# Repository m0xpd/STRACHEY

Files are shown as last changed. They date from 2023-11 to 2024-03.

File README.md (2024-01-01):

# STRACHEY

<p width=100%, align="center">
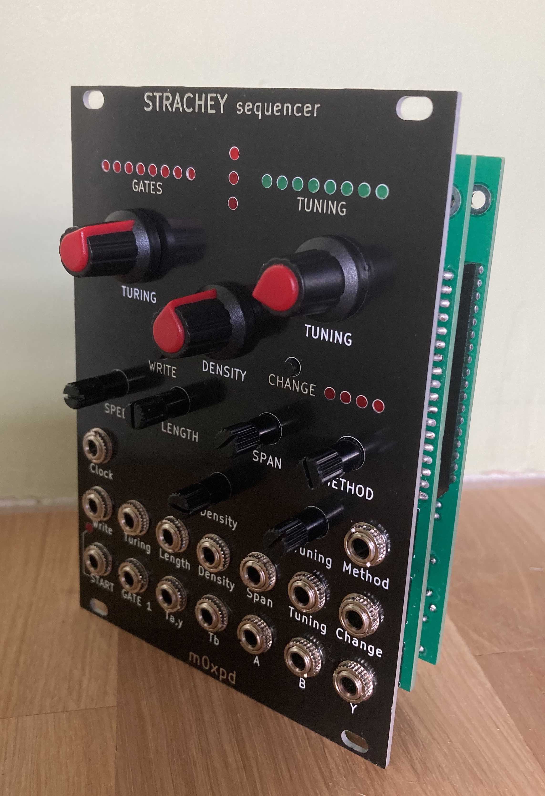
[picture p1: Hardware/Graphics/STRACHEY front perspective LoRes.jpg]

</p>

STRACHEY is a new kind of sequencer for electronic music applications. 

STRACHEY's novelty is two-fold: 
* it directly implements my [tuning strategy](https://github.com/m0xpd/TuningStrategyForVoltages) for Klee-type sequencers and
* it introduces a dynamic [Permutation Matrix](https://en.wikipedia.org/wiki/Permutation_matrix) between the gates and the weights, adding a new dimension of variability

I you wish to build one, or if you're just curious, you can read or download [details of the hardware, including PCB and front panel designs](https://github.com/m0xpd/STRACHEY/tree/main/Hardware) and [a listing of the controller code](https://github.com/m0xpd/STRACHEY/tree/main/Controller).

There are some [specifications here](https://github.com/m0xpd/STRACHEY/blob/main/README.md#specifications) and some details of [Calibration and Configuration here](https://github.com/m0xpd/STRACHEY/blob/main/README.md#calibration-and-configuration). 

I have produced an [Introductory video](https://youtu.be/6UQzKo1PWnU), which describes and demonstrates STRACHEY in detail. 

Further description of STRACHEY follows below.

STRACHEY is published under a Creative Commons BY-SA 4.0 [License](https://github.com/m0xpd/STRACHEY/blob/main/LICENSE.txt). 

# Background

The STRACHEY sequencer is named for [Christopher Strachey](https://en.wikipedia.org/wiki/Christopher_Strachey), who (amongst many other accomplishments) was the first person in England to [program a computer to make music](https://link.springer.com/chapter/10.1007/978-3-319-53280-6_8), leading to the world's [first recording of computer-generated music](http://curation.cs.manchester.ac.uk/digital60/www.digital60.org/media/mark_one_digital_music/mark_one_digital_music.mp3).

Christopher Strachey developed [one of the world's first computer games](https://historyofinformation.com/detail.php?entryid=3731), and developed the programming language CPL, a precursor of C (which is used in the code which runs this STRACHEY sequencer).

STRACHEY implements my [Tuning Strategy for Klee-type Sequencers](https://github.com/m0xpd/TuningStrategyForVoltages) and, as such, 
it is directly inspired by Music Thing Modular's [Turing Machine](https://www.musicthing.co.uk/Turing-Machine/) and its [Voltages expander](https://www.musicthing.co.uk/Turing-Volts-Expander/). STRACHEY was built on my own experiences and habits, formed when using the Turing Machine with its Voltages expander; STRACHEY tries to capture and make accessible all which I found *musically useful* within the vast space covered by the Turing Machine. 

STRACHEY contains an implementation of the Turing Machine ('TM'). The control labelled "TURING" at top left of the module (and the associated CV input) is the equivalent of the large, conspicuous knob on the original TM hardware, and operates in exactly the same way. 

STRACHEY offers (almost) all the features of the original hardware, including the ability to interface to expanders, such as [Pulses](https://www.musicthing.co.uk/Turing-Pulse-Expander/), [Volts](https://www.musicthing.co.uk/Turing-Volts-Expander/) and even [Voltages](https://www.musicthing.co.uk/Turing-Volts-Expander/). It even adds several new features to its TM implementation (such as the START output and CV control over both the Length parameter and the Write function).

More importantly, STRACHEY directly implements the fixed tunings presented in my [Tuning Strategy](https://github.com/m0xpd/TuningStrategyForVoltages), without the need to set these up on the sliders of a Voltages expander, which is a laborious and delicate task. This offers opportunity to quickly expand and develop the tunings (e.g. using octave expansions) and - uniquely - to instantly *move between* the tunings, allowing modulations and "chord progressions" to be explored. However, STRACHEY does more...

STRACHEY has three channels of analog output: A, B and Y, all of which derive their timing from a master clock. 

STRACHEY's clock signal can be applied from an external source to the Clock input (as in the TM). In the absence of an external signal, a clock is generated by a simple oscillator integral to STRACHEY. Outputs A and Y both appear on every beat of this clock.

Channel Y is the conventional TM 'OUT' signal, formed of a weighted sum of the TM's gates 1:8  (the weights being an exponential series, proportional to 1, 0.5, 0.25, 0.125, ...). STRACHEY's Y output is scaled to range between 0 and 5V and is provided for use as a general modulation source.

Channel A is the main STRACHEY output. It produces an output (to be interpreted as a 1V/octave pitch CV signal) at the rate of the main signal clock. 
It is set to span six and a half octaves at a resolution of 51 quantisation steps per semitone, meaning there will be less than a 2 cent error in tuning over the system's range, if we can trust the DAC linearity (experience to date has been entirely positive).

# STRACHEY Tunings

The control at top right of the panel, labelled "TUNING", and the associated CV input choose between 24 pre-detemined settings of "weights", equivalent to the slider settings on a Turing Machine 'VOLTAGES' expander, or the knobs on any other sequencer. These weights, together with the gates generated by the Turing Machine, form the channel A (and channel B) outputs.

The weight settings are called 'Tunings' and they are chosen from my [Tuning Strategy](https://github.com/m0xpd/TuningStrategyForVoltages) to be those which give an output which I found to be musically useful. 

The tunings are arranged in three Banks; 
* Bank A are "Basic" Tunings, mainly yielding arpeggiated chords 
* Bank B are mainly MODES
* Bank C are mainly [Symmetric Scales](https://en.wikipedia.org/wiki/Symmetric_scale)

The tunings presently implemented in the code are tabulated below:

| Tuning# | Description | Tuning Strategy # | Bank | Display |
|---|---|---|---|---|
| 0 | Root & Fifth | (3) | A | 10000000 |
| 1 | AEOLIAN (Natural minor) | 14 | A | 01000000 |
| 2 | Minor 7th | 5 | A | 00100000 |
| 3 | Major 7th | 6 | A | 00010000 |
| 4 | Diminished 7th | 8 | A | 00001000 |
| 5 | Augmented | 7 | A | 00000100 |
| 6 | "Sus 7th" Feel | 10 | A | 00000010 |
| 7 | "9th" Feel | 9 | A | 00000001 |
| 8 | Root & Fifth | (3) | A | 10000000 |
| 9 | AEOLIAN | 14 | B | 01000000 |
| 10 | DORIAN | 11 | B | 00100000 |
| 11 | PHRYGIAN | 13 | B | 00010000 |
| 12 | IONIAN | 18 | B | 00001000 |
| 13 | Hexatonic, IONIAN, missing 7th degree | 22 | B | 00000100 |
| 14 | Octatonic, IONIAN, with added flat 5 | 20 | B | 00000010 |
| 15 | Hexatonic, with no third | 23 | B | 00000001 |
| 16 | Root & Octave | (3) | C | 10000000 |
| 17 | Tritone | (15) | C | 01000000 |
| 18 | Augmented | 7 | C | 00100000 |
| 19 | Diminshed | 8 | C | 00010000 |
| 20 | Whole-tone | 16 | C | 00001000 |
| 21 | Chromatic | 17 | C | 00000100 |
| 22 | Major (IONIAN) | 19 | C | 00000010 |
| 23 | Descending Major Scale | N/A | C | 00000001 |

'Bank' (fourth column of the table above) is indicated by the stack of three LEDs in the centre, top of the module. Bank A is indicated by the lowest LED.

'Display' (final column of the table) shows the pattern illuminated on the 'TUNING' LEDs.

A bracket surrounding the Tuning Strategy number in the table above indicates that it is slightly modified relative to the tuning given in the Tuning Strategy document (e.g. by the addition of a second flattened fifth to the tritone, to allow it to sound the octave). Tuning # 23 is unusual and is not derived from the Tuning Strategy. It is included as a test/demonstration case. Tuning # 23  does generate 12TET outputs, but it doesn't produce a particularly pleasant output when used with a gate sequences having more than one active gate. It is intended to be used with a **single active gate**, when it will be heard as a descending major scale.

Some tunings are intentionally repeated in the table above for ease of use - some *appear* repeated, but are different forms (such as the several versions of IONIAN [major scale] tuning which are presented).

STRACHEY goes on to develop outputs using these initial tunings by a series of modifications and manipulations, which are now described.

# Weight Modifications in STRACHEY

Channel B is the secondary STRACHEY output. It operates at the same pitch resolution as channel B but (for reasons which are explained below), the pitch range of channel B is lower than that of channel A. 

The outputs on channel B occur at the onsets of a Euclidean pattern, generated by STRACHEY. This pattern has length determined by the Turing Machine's LENGTH parameter and density determined by STRACHEY's DENSITY controls. LENGTH and DENSITY are both controllable by front panel potentiometers - "DENSITY" is the third of STRACHEY's main potentiometers. Both Length and Density and can further be controlled by CV inputs. 

This makes the onsets of the output from channel B: 

* a subset of the beats of the main system clock,
* a pattern which has rhythmic interest and
* a pattern which can be made to change (by modulating the Density CV input)

The same gate sequence (generated by the Turing Machine) and the same initial weight vector (selected by the TUNING controls) produce the channel A and B outputs, so the *set of allowed pitches* are the same (as described at tedious length in the [Tuning Strategy](https://github.com/m0xpd/TuningStrategyForVoltages)). However, STRACHEY can apply two modifications to the weight vector used in forming the output from channel A. 

Firstly, the initial weight vector can be permuted (i.e. changed in order) before channel A's output is formed, during operation, giving STRACHEY an entirely new dimension of variability relative to other Klee sequencers, including the Turing Machine. STRACHEY performs these permutations using different "Methods", selected by the METHOD control (and associated CV input). These permutations are triggered by "Change" commands, issued either by the CHANGE pushbutton (or the associated CV input). A fuller description appears below. 

Secondly, the initial weight vector can be subject to additions, each of which cause an octave increase in pitch span (under control of the SPAN controls - both potentiometer and CV input). These extend the pitch range of the channel A output, using the same notes as specified in the original tuning, but allowing them to range over a wider span. 

Neither the permutations or the octave extensions of channel A's weight vector are applied to channel B.

So - channel B has a generally reduced pitch span compared to channel A (as there is no octave extension added via SPAN) and there is no variation introduced by permutation. It also has less dense onsets; it '*samples*' notes from the set of pitches within the fundamental range of channel A's pitch distribution on a rhythmic sub-pattern of variable DENSITY. Channel B is particularly useful for forming bass or melody against a fuller, arpeggiated 'continuo' from channel A.

# Permuting the Weights of a Step Sequencer

The idea of introducing permutation between the gates and weights of a Random Looping Sequencer is (as far as I'm aware) novel. 

The practice of stopping and single-stepping a sequencer is, of course, familiar and I have [demonstrated some other effects](https://www.youtube.com/watch?v=kFBzPTS7XLM) obtained with multi-rate or asynchronous scanning of a Klee sequencer. But synchronous permutation of the mapping between gates and weights is less familiar. One notable exception is the idea of reversing the scan direction of a sequencer, (which can be expressed as a simple permutation) and is seen on both 'DIY' sequencers from [MFOS](https://musicfromouterspace.com/analogsynth_new/SEQ16_2006/SEQ16_2006.php) and commercial units from e.g. [Doepfer](https://doepfer.de/a154.htm). 

STRACHEY can - of course - reverse its scan direction, either by flipping the current permutation (Method# 13)  or by resetting to a 'reversed' version of the starting weight vector (Method# 12).

There are other synchronous permutations worth exploring.

Back in 2017 I made a gate sequencer 

<p width=100%, align="center">
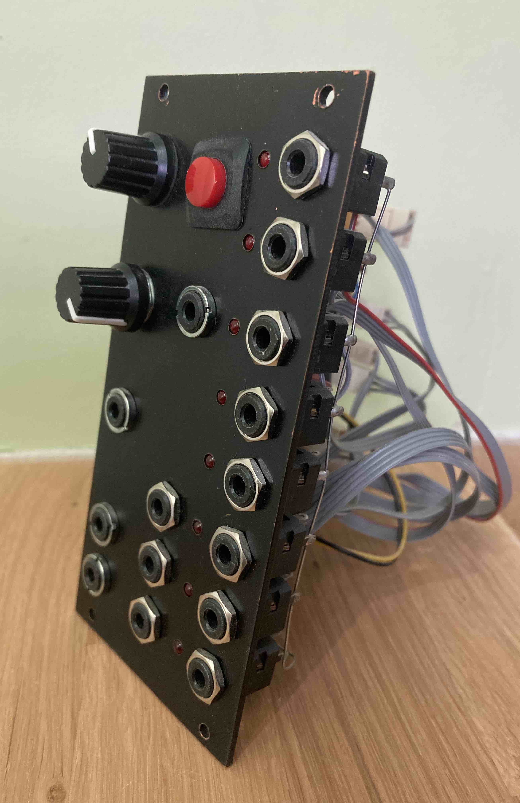
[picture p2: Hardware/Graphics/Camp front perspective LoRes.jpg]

</p>

which was inspired by patterns used in [Change Ringing](https://en.wikipedia.org/wiki/Change_ringing), a perversely English way of sounding the bells of a Church. These patterns are called "Methods". The key ingredient of Change Ringing is an exploration of the permutations by which a number of bells may be sounded in sequence. In the case of my module, I implemented four of the traditional "Methods"  ([Rounds](https://jaharrison.me.uk/Ringing/Glossary/R.html#rounds), [Plain Hunt](https://en.wikipedia.org/wiki/Plain_hunt), [Grandsire](https://en.wikipedia.org/wiki/Grandsire) and [Plain Bob](https://www.ringing.info/plp/pb8/index.html)) to trigger any number of gates (any "[Stage](https://jaharrison.me.uk/Ringing/Glossary/S.html#stage)") between 4 and 8. Although the sequencer was made as a percussion trigger source rather than in attempt to simulate the sound of church bells, I added - for the purposes of demonstration - two 1V/octave pitch CV outputs, one set to be typical of the diatonic tuning of a ring of bells and one set (for comedic purposes!) to a minor pentatonic scale. 

I was, therefore, entirely familiar with the idea of using permutations in general (and permutations from bell ringing in particular) in a step sequencer. The only further inventive step for me in the development of STRACHEY was the extension of these ideas to a Klee-type sequencer. 

That step involved the introduction of a [permutation matrix](https://en.wikipedia.org/wiki/Permutation_matrix) between the gates and the weights in the scalar product which forms the sequencer output - for both a conventional sequencer and a Klee sequencer. (The actual coding doesn't require matrix methods - it is achieved in [the code](https://github.com/m0xpd/STRACHEY/blob/main/Controller/Code/STRACHEY_Sequencer_1v0.ino) just by indexing within the scalar product. The matrix is just a conceptual and mathematical convenience.)

STRACHEY uses a fixed number of weights ("Stage") to form the pitch output from the gate vector: the eight inherited from the 8 sliders on MTM's Voltages expander. If these 8 weights are seen in analogy with 8 bells (which is the standard stage in a larger bell tower for change ringing), some of STRACHEY's methods for permuting the weights can be related to bell ringing.

STRACHEY currently implements two standard bell ringing methods; "[rounds](https://jaharrison.me.uk/Ringing/Glossary/R.html#rounds)" (which is the bell-ringing term when the permuatation matrix is fixed at the identity matrix)  and "Plain Hunt Major" ('Plain Hunt' is - as we've seen - a [standard algorithm](https://en.wikipedia.org/wiki/Plain_hunt) for changing the permutation matrix and 'Major' is [bell-ringing jargon](https://jaharrison.me.uk/Ringing/Glossary/M.html#major) indicating that the algorithm is applied on a stage of 8 weights) . 

In both cases, STRACHEY will implement [plain courses](https://jaharrison.me.uk/Ringing/Glossary/P.html#plaincourse) of these methods (just as my gate sequencer did back in 2017). However, in STRACHEY there is possibility to introduce variation, described below, similar to a bell-ringing ['single' change](https://jaharrison.me.uk/Ringing/Glossary/S.html#singlechange), by which the hunt may be changed, to extend the sequence to a longer pattern. By this means, STRACHEY can be set in rounds (Method# 0) or plain hunt (Method# 6), using the METHOD controls (potentiometer or CV), and set to run on course, with occasional calls to a random 'single' by changing the METHOD to the random single change call (Method# 5 - all the METHODs are tabulated below).  

STRACHEY can introduce variation by other means.

STRACHEY can *sort* the weights in pitch order, either descending or ascending. It can do this in two ways - either in an immediate sort or as one step of a [bubble sort](https://en.wikipedia.org/wiki/Bubble_sort) (such that a number of successive number of calls to this process are required to achieve the final sort). Each change is made at the start of the cycle (of length determined by the Turing Machine's LENGTH parameter), if requested by an 'Change' input during the previous cycle. 

STRACHEY can also reset the permutation matrix (to the identity matrix - playing 'rounds' in bell-ringing parlance), can fully randomise the permutation matrix or can introduce one random swap in the permutation matrix associated with swapping position of a random weight with one of its neighbours. (This last method is the analogy with the underlying technique in [Call-changing](https://en.wikipedia.org/wiki/Call_changes) - the 'single' described above,  but is - in this case - randomised rather than designed.)

A table of all the (currently implemented) METHODS is presented below, along with the boundaries for the voltages which should be applied at the Method CV input if it is desired to select the METHOD using this means. 

|  Method # |  Description |  Vlow |  Vhigh  |
|---|----|----|----|
|  0  | Reset |  0  |  0.3125  |
|  1  | SortAscending |  0.31  |  0.63  |
|  2  | SortDescending |  0.63  |  0.94 |
|  3  | SingleSortUp |  0.94  |  1.25  |
|  4  | SingleSortDown |  1.25  |  1.56  |
|  5  | RandomSingle |  1.56  |  1.88  |
|  6  | PlainHunt |  1.88  |  2.19  |
|  7  | *Not Implemented*  |  2.19  |  2.5  |
|  8  | RotateR |  2.5  |  2.81  |
|  9  | RotateL |  2.81  |  3.13  |
|  10  | *Not Implemented* |  3.13  |  3.44  |
|  11  | *Not Implemented* |  3.44  |  3.75  |
|  12  | Reverse |  3.75  |  4.06  |
|  13  | Flip |  4.06  |  4.38  |
|  14  | *Not Implemented* |  4.38  |  4.69  |
|  15  | Shuffle |  4.69  |  5  |

Note that the **Method #** is displayed (in binary) on the four red LEDs above the METHOD control. 

The METHOD display will flash after a CHANGE call is made (either by pressing the CHANGE button or pulling down the Change CV input) until the selected subroutine call is completed at the start of the next cycle. For continuous methods such as running Plain Hunt (Method # 6) or continuously flipping the order on successive passes (Method # 13) it is appropriate to keep Change continually asserted (e.g. by tying the Change CV low). The Method LEDs will then flash continually, pausing only on the first beat of each cycle when START=1.      

# Calibration and Configuration

STRACHEY has one aspect requiring **calibration** before it will operate correctly; trimmers TR1 and TR2 must be adjusted to ensure that outputs A and B (respectively) are correctly tuned in V/octave terms. The MC4922 DAC is operated over a 0:5V output range, but the DAC's output is further passed through non-inverting amplifier stages (IC4D for channel A and IC4 C for channel B) with gain of 2. The code expects the full-scale 5V output from the DAC to be broken down into 2^12 steps and uses 51 steps per semitone. 

Accordingly, I have calculated that *in an ideal system* the trimmers should be set to a ratio of 0.669 (i.e. a 1k trimmer should have the lower leg of the potential divider set to 669 Ohms). In reality, where all the components have tolerances and there are some offsets etc., this ratio will not be quite correct - hence the decision to use trimmers rather than fixed resistors. I just measured my own trimmers (which have - so far - been set only 'by ear') and found that TR1 is set at a ratio of 0.696 and TR2 is at a ratio of 0.689. Start off at 0.7 and you'll be close!

There is one feature of STRACHEY that requires **configuration**. There is provided on the main board an Turing Machine expansion port in the standard  Music Thing Modular format. It can be used *either* as a GATES expander (by bridging pins 1 and 2 of JP3, which connects the 'EXP_SEL' (Expander Select) line to 5V) or as a PULSES expander (by bridging pins 2 and 3 of JP3, which connects the 'EXP_SEL' (Expander Select) line to the main clock). The GATES expander port is used with [VOLTS](https://www.musicthing.co.uk/Turing-Volts-Expander/) and [VOLTAGES](https://www.musicthing.co.uk/Turing-Voltages-Expander/) and the PULSES expander port is used with [PULSES](https://www.musicthing.co.uk/Turing-Pulse-Expander/). 

I prefer to use STRACHEY with a [PULSES](https://www.musicthing.co.uk/Turing-Pulse-Expander/) module to expand the time-domain and rhythmic capability of the sequencer; STRACHEY already produces a rich set of analog (pitch) outputs. Accordingly, I set up my expander port as a PULSES expander.

The red stripe on the expander ribbon cable goes towards the bottom edge of STRACHEY's Main board (I forgot to put a marker on the silkscreen). 

# Specifications

**Width:** 

STRACHEY is **18HP wide**.

**Depth:**

STRACHEY extends **43 mm** behind the [front panel](https://github.com/m0xpd/STRACHEY/blob/main/Hardware/Panel/README.md) when a conventional Eurorack power header **with strain relief** is inserted (this is the same depth as the [original Turing Machine](https://www.musicthing.co.uk/Turing-Machine/)).

If your power header doesn't have a strain relief (which is probably more typical, judging by the power cables delivered with commercial modules) the depth is limited by the Arduino's USB receptacle; in this situation STRACHEY extends **42mm** behind the [front panel](https://github.com/m0xpd/STRACHEY/blob/main/Hardware/Panel/README.md).

**Power Consumption:**

| Power Rail | Current |
|---|---|
| +12V | **48mA** |
| -12V | **10mA** |
| 5V | **0** |

(peak currents, measured with nothing connected to STRACHEY's expansion port).

**Miscellaneous:**

All inputs are protected against over/under voltage.

Most of the CV inputs are intended to operate over a 0:5V control range. However, the Density and Method CV inputs are applied to attenuverters; these inputs will respond to signals spanning the entire bipolar Eurorack voltage range (+/- 12V). 

It is my habit to set up my attenuverter controls such that full counterclockwise rotation gives unity gain and full clockwise rotation gives gain of -1. This is **opposite to common practice**.

The external Clock input is triggered by signals exceeding an **(upward) threshold of 1.25V**.

The Change CV input is ACTIVE LOW - it must be pulled low to call one of the CHANGE METHODs and held high to retain the status quo. This input similarly responds to signals exceeding an (upward) threshold of 1.25V but, given the ACTIVE LOW nature of this control, the **downward threshold of 1.05V** is more important.

The Write input is usually held at mid-voltage (2.5V) by an internal resistor network. When an input is applied to the Write CV jack, this 2.5V is disconnected, so any external device should provide a voltage close to 2.5V. Pulling this voltage **below 0.49 V will write a '0'** and **above 4.39 V will write a '1'**.

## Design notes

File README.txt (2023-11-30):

# Controller

This folder contains details of the code which implements the STRACHEY sequencer.

I originally intended to build the code on an STM32, expecting that both the I/O requirements and the complexity of the application would take me beyond the scope of simpler microcontrollers. 
However, I found that I could just fit the features I had targetted into code for a simple little ARDUINO NANO - so that is what has been used.

There is an Arduino script in the Code folder.

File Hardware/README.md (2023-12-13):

# Hardware
This folder contains details of STRACHEY's hardware.

STRACHEY is implemented using through-hole components mounted on two PCBs, each measuring 88 * 108 mm.

The majority of the electronics, incuding the Arduino Nano, are mounted on the '[main board](https://github.com/m0xpd/STRACHEY/blob/main/Hardware/Main/ReadMe.md)', whilst user-interface components are mounted on the '[control board](https://github.com/m0xpd/STRACHEY/blob/main/Hardware/Control/README.md)'.

<p width=100%, align="center">
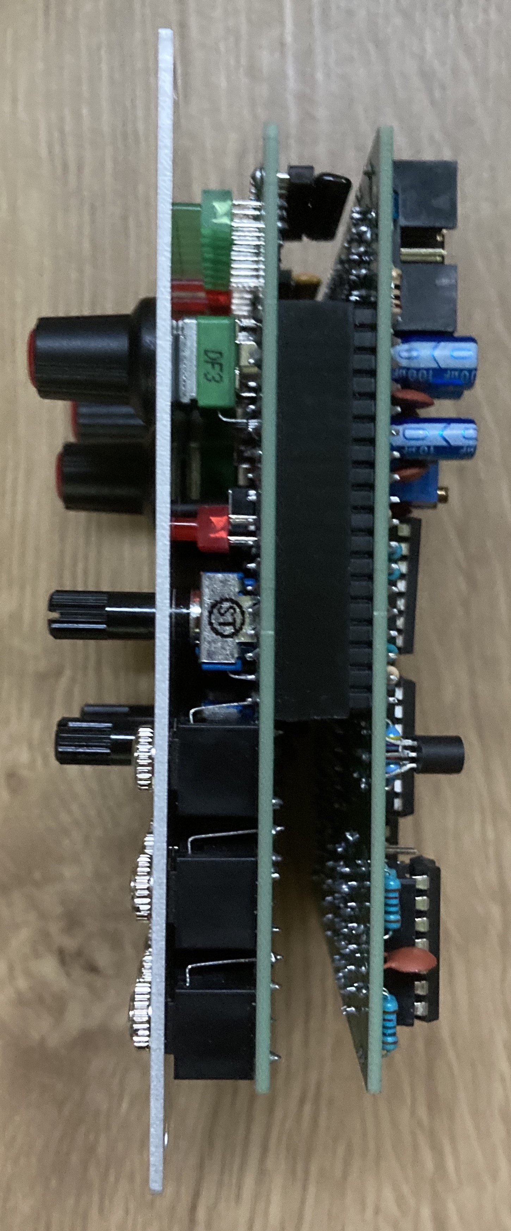
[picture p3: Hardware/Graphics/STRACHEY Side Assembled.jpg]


The boards are joined electrically by two 18-way 0.1 inch headers and an 8-way 0.1 inch header. I cut the 18-way headers down from 40-way headers (of which I keep a stock). There are holes for M3 bolts to secure the boards together for those taking the system "on the road" - people using the system in a static installation will find that the headers alone provide a secure mechanical interface. The component board is secured to the front panel by the sixteen "Thonkiconn" jack sockets and the three 9mm potentiometers.  

The system was developed in [KiCad](https://www.kicad.org/) (the first electronic project I have undertaken using this software). KiCad projects for the boards are presented in the Main and Control folders, along with schematics, BoMs and limited circuit descriptions. A [Front Panel design](https://github.com/m0xpd/STRACHEY/blob/main/Hardware/Panel/README.md) is also available as a KiCad project.

All the hardware is published under [License](https://github.com/m0xpd/STRACHEY/blob/main/LICENSE.txt).

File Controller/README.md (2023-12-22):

# Controller

This folder contains details of the code which implements the STRACHEY sequencer.

I originally intended to build the code on an STM32, expecting that both the I/O requirements and the complexity of the application would take me beyond the scope of simpler microcontrollers. 
However, I found that I could fit the features I had targetted into code for a simple little [ARDUINO NANO](https://docs.arduino.cc/hardware/nano) - so that is what has been used.

There is an [Arduino script](https://github.com/m0xpd/STRACHEY/blob/main/Controller/Code/STRACHEY_Sequencer_1v0.ino) in the Code folder.

The code includes a Euclidean pattern generator written by Tom Whitwell, which I originally discovered on [Craig Lee's site](https://clsound.com/euclideansequenc.html)

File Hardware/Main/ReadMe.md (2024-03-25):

# Main Board

This folder contains details of STRACHEY's Main Board which you seen below (component side) 

<p width=100%, align="center">
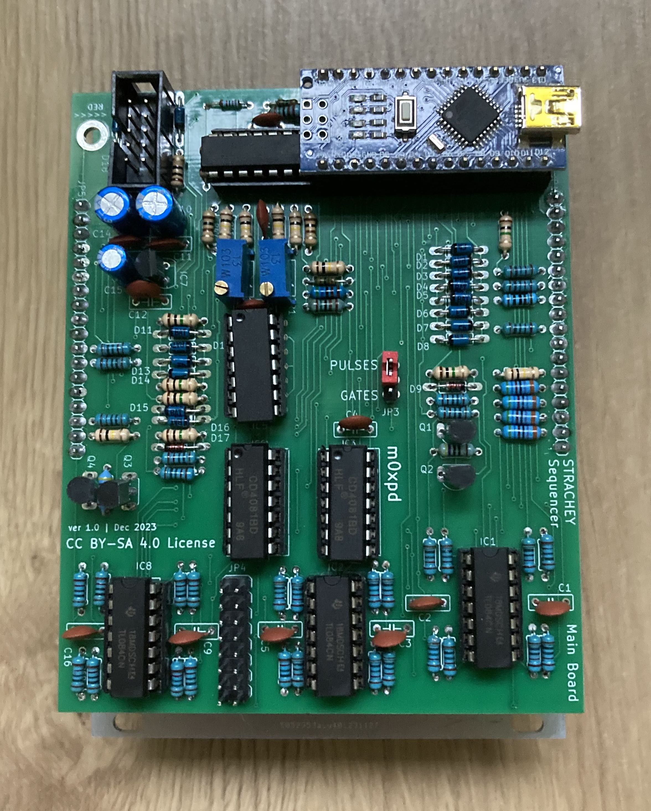
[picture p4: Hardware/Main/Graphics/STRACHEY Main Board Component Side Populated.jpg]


You can download the main board's schematic as a [.sch file](https://github.com/m0xpd/STRACHEY/blob/main/Hardware/Main/main%20board.kicad_sch) into your PCB program (KiCad etc) or see a [PDF version](https://github.com/m0xpd/STRACHEY/blob/main/Hardware/Main/main%20board%20schematic.pdf).

The Main Board hosts power supplies, the Arduino Nano, the DACs, output drivers, input protection and conditioning circuits, the Turing Machine Expansion port, and interface to the control Board.

I am new to KiCad and the BoM generator produces output in .csv format. I have decided to save this information [as an Excel file](https://github.com/m0xpd/STRACHEY/blob/main/Hardware/Main/Strachey%20main%20board%20BoM.xlsx) to retain some edits I made. 

There are a few minor points of potential confusion in the BoM (e.g. where I gave some resistors value "10K" and others "10k"), but I'm sure you'll figure it out. Note particularly that the two multi-turn trimmers, TR1 and TR2  (the blue components seen in the photo above) are listed as having value 1k in the schematic and the BoM. I decided to use 10k components,as I had them to hand. Any value above 1k (and up to 100k) will work fine. There is some description of calibrating the trimmers [here](https://github.com/m0xpd/STRACHEY/tree/main#calibration-and-configuration).

I am grateful to 'Harpooneer' who is building a STRACHEY sequencer - he has pointed out that the Main PCB is too congested around the trimmers TR1 and TR2 and we have discussed the build. TR1 and TR2 should be Bourns 3296W (or equivalent) types. They do just fit (as you see in the image above) but it certainly is a squeeze! I found assembly of the prototype easier if you fit the trimmers before other adjacent componenents (R37, R43, R44 and R45) and ensure that C8 is a slim disc ceramic. 

The [.pcb file](https://github.com/m0xpd/STRACHEY/blob/main/Hardware/Main/main%20board.kicad_pcb) and [.pro file](https://github.com/m0xpd/STRACHEY/blob/main/Hardware/Main/main%20board.kicad_pro) (togther with the [.sch file](https://github.com/m0xpd/STRACHEY/blob/main/Hardware/Main/main%20board.kicad_sch) ) constitute a KiCad project, which define the Main board. 

[JLCPCB](https://jlcpcb.com) made the boards for my prototype and did their usual excellent job (usual disclaimer) - you can see the top and bottom sides of the Main Board below:

<p width=100%, align="center">
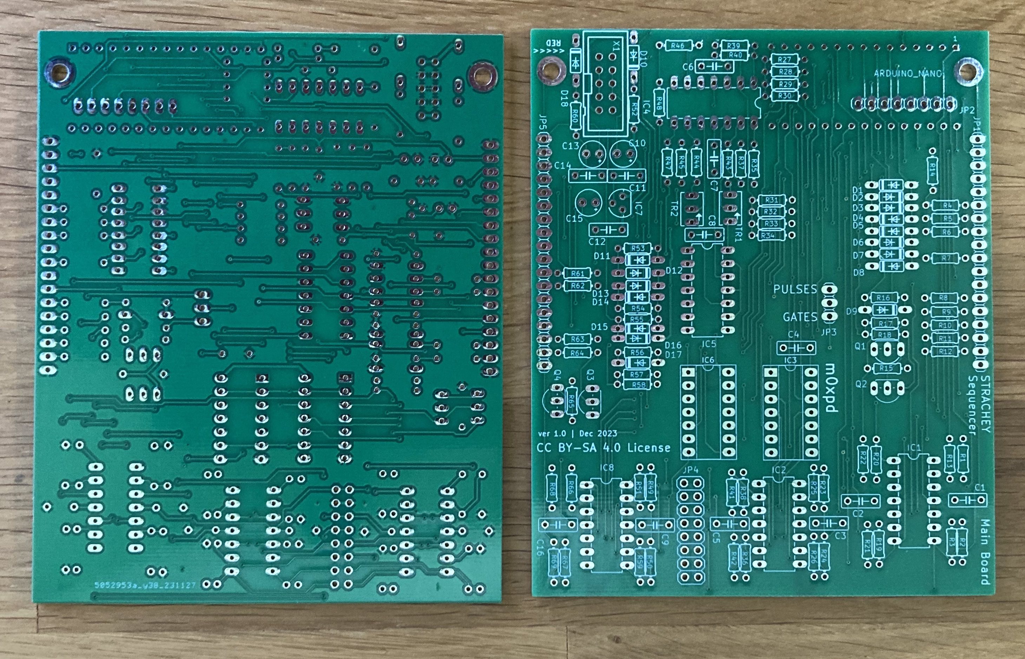
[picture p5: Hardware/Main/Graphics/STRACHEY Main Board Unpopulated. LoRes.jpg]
  
</p>
  
There is description of how to configure the expansion port (the 2*8 pin header, JP4, seen at the bottom of the main board) by setting shorting links on JP3 (the 3 pin header, near the middle of the main board) [here](https://github.com/m0xpd/STRACHEY/tree/main#calibration-and-configuration).

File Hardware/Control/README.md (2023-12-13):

# Control Board

This folder contains details of STRACHEY's control board, which you see below (component side).

<p width=100%, align="center">
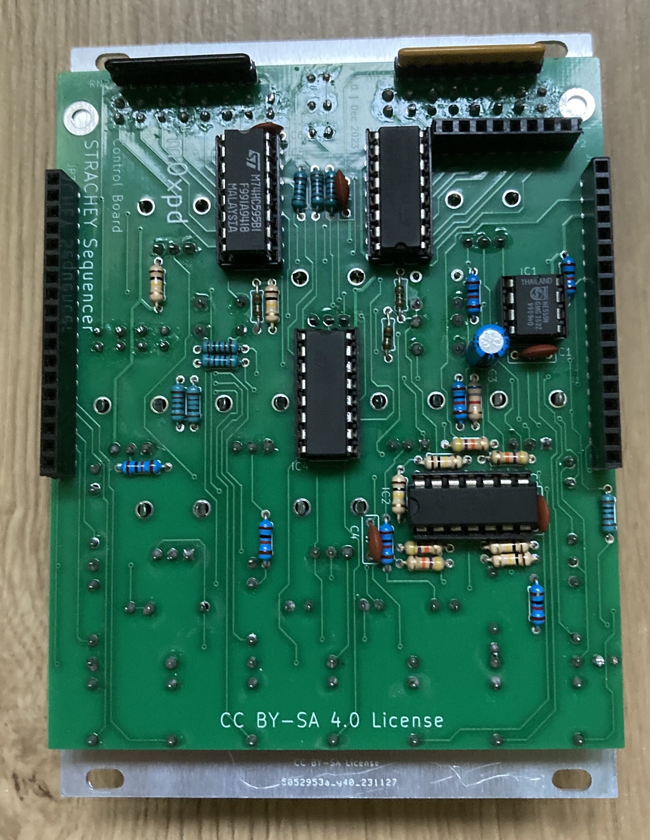
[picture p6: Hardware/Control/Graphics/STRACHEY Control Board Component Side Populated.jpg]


The bottom side of the control board hosts all the jacks, pots, tactile switches, and 24 LEDs, which mate with the Front Panel and form the user interface.

You can download the main board's schematic as a [.sch file](https://github.com/m0xpd/STRACHEY/blob/main/Hardware/Control/control%20board.kicad_sch) into your PCB program (KiCad etc) or download a [PDF version](https://github.com/m0xpd/STRACHEY/blob/main/Hardware/Control/control%20board%20schematic.pdf).

In addition to the front panel / UI components mentioned above, the control board hosts three 74HC595 serial in, parallel out shift registers. One of these communicates gate signals from inside the Aruino to the physical world - for display on the LEDs, for application to the DAC which drives the channel Y output, and for gate 1 output. The other 2 shift registers service all the other status indication lights. 

The control board also hosts a single quad op-amp, which implements the attenuverter and mixer stages that form the TUNE and DENSITY controls.

STRACHEY is my first electronic project in KiCad and I am new to the BoM generator's .csv output format. I have decided to save this information [as an Excel file](https://github.com/m0xpd/STRACHEY/blob/main/Hardware/Control/Strachey%20Control%20Board%20BoM.xlsx) to retain some edits I made. 

There are a few points in the BoM which should be emphasised, as the information is not made explicit in the schematic.

Firstly, whilst all potentiometers use the 9mm snap-in vertical footprint, only three are the usual 'Alpha' pots. These are VR2 (The TUNING Control), VR5 (The DENSITY control) & VR8 (The TURING Control). The remaining potentiometers are Song Huei 9mm Trimmers

Secondly, the momentary action 6mm 'tactile' switches, SW1:SW3 should be of 13mm size (or taller). The tip of the shaft of a 13mm switch protrudes through the front panel by a little over 1.5mm, which looks and feels right. If you want more, fit a 14mm or 15mm switch.

Finally, although the PCB shows a 3mm LED footprint, the front panel is drilled to accept 2mm "Lighthouse-type" LEDs. I have chosen to use green LEDs for the TUNING indication (LEDs 13:17, 19, 21 & 23) whilst the rest are red. Series resistors of 1K for the green and 10k for the red work well with the particular LEDs I'm using - hence the component values for the resistor networks RN1 & 2 etc.. However, you should check **YOUR** LEDs for appropriate brightness before fitting the resistors. 

The [.pcb file](https://github.com/m0xpd/STRACHEY/blob/main/Hardware/Control/control%20board.kicad_pcb) and [.pro file](https://github.com/m0xpd/STRACHEY/blob/main/Hardware/Control/control%20board.kicad_pro) (togther with the [.sch file](https://github.com/m0xpd/STRACHEY/blob/main/Hardware/Control/control%20board.kicad_sch) ) constitute a KiCad project, which define the Main board. 

[JLCPCB](https://jlcpcb.com) made the boards for my prototype and did their usual excellent job (usual disclaimer) - you can see the top and bottom sides of the Control Board below:

<p width=100%, align="center">
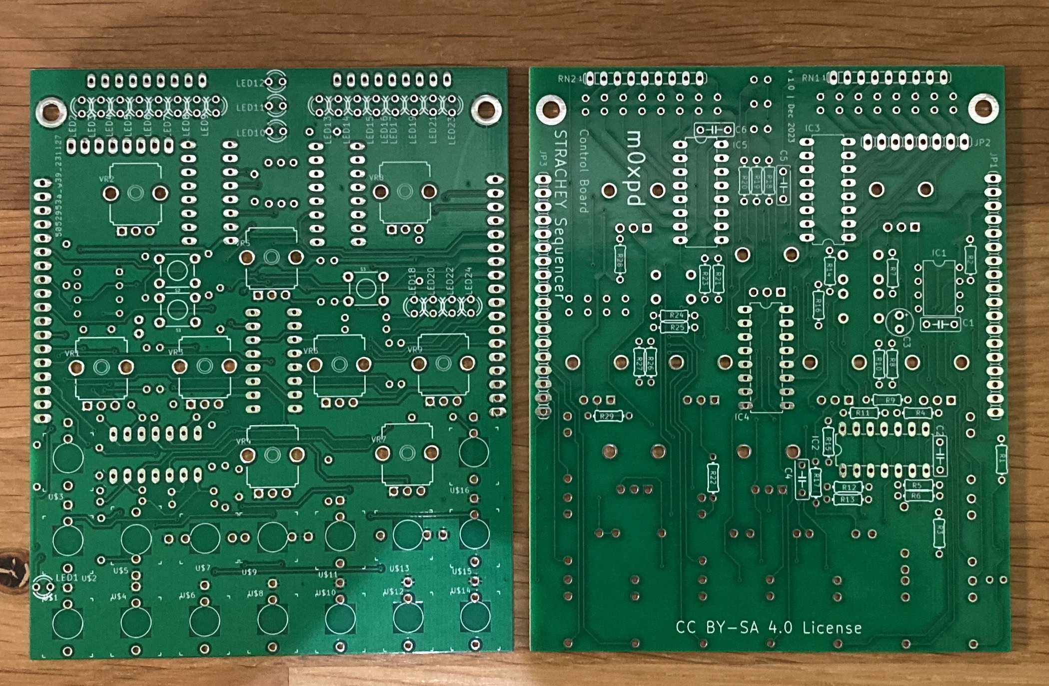
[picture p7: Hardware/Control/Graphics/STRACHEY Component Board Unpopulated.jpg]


# Assembly

As with all such 'control boards' which mate with an accurately prepared [front panel](https://github.com/m0xpd/STRACHEY/blob/main/Hardware/Panel/README.md), it is advisable to fit the panel-mounting components into BOTH the PCB and panel *DURING soldering*, to ensure correct alignment. 

This is **particularly important** with all the tiny LEDs in STRACHEY, as alignment is critical!

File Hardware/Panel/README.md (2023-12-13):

# Front Panel

This folder describes STRACHEY's front panel.

I designed the panel in KiCad. I've been using KiCad for panel design for over a year so (unlike in electronic aspects of this project) I can't claim to be a new user - but I can confirm that KiCad is great for designing front panels.

There is a [.pcb file](https://github.com/m0xpd/STRACHEY/blob/main/Hardware/Panel/Strachey%20Panel.kicad_pcb) and a [.pro file](https://github.com/m0xpd/STRACHEY/blob/main/Hardware/Panel/Strachey%20Panel.kicad_pro) which together make a KiCad project for the Panel (the schematic is, of course, trivial as the panel has no electrical connections).

These add up to a panel which [JLCPCB](https://jlcpcb.com) made for my prototype system in aluminium in black with white silkscreen (as per the design). JLC did their usual excellent job (usual disclaimer), but this white on "black on an aluminium substrate" recipe is very expensive. If you want to save money, you should either change the design to black on white on an aluminium panel or change to an FR4 panel. 

You can see the front and rear sides of the prototype panel in the image below:
<p width=100%, align="center">
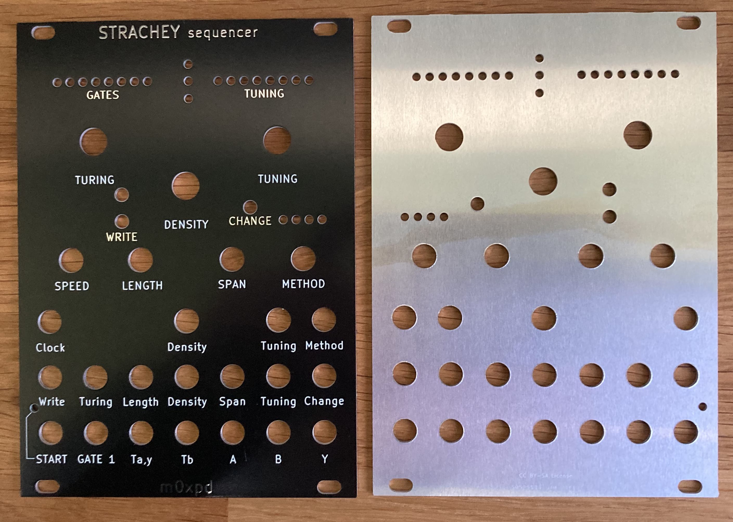
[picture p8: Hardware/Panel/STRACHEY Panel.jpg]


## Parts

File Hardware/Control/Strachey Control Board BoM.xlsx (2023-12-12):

Source: | xxx
Date: | xxx
Tool: | Eeschema 7.0.9
Generator: | /Applications/KiCad/KiCad.app/Contents/SharedSupport/plugins/bom_csv_grouped_by_value.py
Component Count: | 99
Collated Components:
Item | Qty | Reference(s) | Value | Comments | LibPart | Footprint | Datasheet | DNP
1 | 5 | C1, C2, C4, C5, C6 | 0.1u |  | control board-eagle-import:C-EU050-025X075 | control board:C050-025X075
2 | 1 | C3 | 4u7 |  | control board-eagle-import:CPOL-EUE2.5-5 | control board:E2,5-5
3 | 2 | H1, H2 | MountingHole_Pad |  | Mechanical:MountingHole_Pad | MountingHole:MountingHole_3.2mm_M3_DIN965_Pad_TopBottom | ~
4 | 1 | IC1 | LM555N |  | control board-eagle-import:555N | control board:DIL08
5 | 1 | IC2 | TL084P |  | control board-eagle-import:TL084P | control board:DIL14
6 | 3 | IC3, IC4, IC5 | 74HC595N |  | control board-eagle-import:74595N | control board:DIL16
7 | 2 | JP1, JP3 |  | 1*18 0.1 inch FEMALE Header | control board-eagle-import:PINHD-1X18 | control board:1X18
8 | 1 | JP2 |  | 1*8 0.1 inch FEMALE Header | control board-eagle-import:PINHD-1X8 | control board:1X08
9 | 24 | LED1, LED2, LED3, LED4, LED5, LED6, LED7, LED8, LED9, LED10, LED11, LED12, LED13, LED14, LED15, LED16, LED17, LED18, LED19, LED20, LED21, LED22, LED23, LED24 |  | 2mm 'Lighthouse' LED LEDs13:17, 19, 21 & 23 GREEN, remainder RED | control board-eagle-import:LED3MM | control board:LED3MM
10 | 8 | R1, R18, R19, R20, R24, R25, R26, R27 | 10k |  | control board-eagle-import:R-EU_0204/7 | control board:0204_7
11 | 7 | R2, R3, R7, R10, R17, R22, R29 | 1k |  | control board-eagle-import:R-EU_0204/7 | control board:0204_7
12 | 4 | R4, R9, R12, R13 | 47k |  | control board-eagle-import:R-EU_0204/7 | control board:0204_7
13 | 6 | R5, R6, R11, R15, R21, R28 | 100k |  | control board-eagle-import:R-EU_0204/7 | control board:0204_7
14 | 1 | R8 | 6k8 |  | control board-eagle-import:R-EU_0204/7 | control board:0204_7
15 | 3 | R14, R16, R23 | 22k |  | control board-eagle-import:R-EU_0204/7 | control board:0204_7
16 | 1 | RN1 | 10k |  | control board-eagle-import:GE08R | control board:SIL9
17 | 1 | RN2 | 1k |  | control board-eagle-import:GE08R | control board:SIL9
18 | 3 | S1, S2, S3 | MOMENTARY-SWITCH-SPST-PTH-6.0MM | 6*6*13 mm momentary action tactile switches | control board-eagle-import:MOMENTARY-SWITCH-SPST-PTH-6.0MM | control board:TACTILE_SWITCH_PTH_6.0MM
19 | 16 | U$1, U$2, U$3, U$4, U$5, U$6, U$7, U$8, U$9, U$10, U$11, U$12, U$13, U$14, U$15, U$16 | THONKICONN_JACK | https://www.thonk.co.uk/shop/thonkiconn/ | control board-eagle-import:THONKICONN_JACK | control board:WQP-PJ301M-12_JACK
20 | 1 | VR1 | A100k | Song Huei Trimmer Pots, eg: https://www.thonk.co.uk/shop/ttpots/ | control board-eagle-import:9MM_SNAP-IN_POT_ | control board:9MM_SNAP-IN_POT
21 | 3 | VR2, VR5, VR8 | B100k | Alpha 9mm pots, eg: https://www.thonk.co.uk/shop/alpha-9mm-pots-vertical-t18/ | control board-eagle-import:9MM_SNAP-IN_POT_ | control board:9MM_SNAP-IN_POT
22 | 5 | VR3, VR4, VR6, VR7, VR9 | B100k | Song Huei Trimmer Pots, eg: https://www.thonk.co.uk/shop/ttpots/

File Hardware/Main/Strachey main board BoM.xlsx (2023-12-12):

Source: | xxx
Date: | xxx
Tool: | Eeschema 7.0.9
Generator: | /Applications/KiCad/KiCad.app/Contents/SharedSupport/plugins/bom_csv_grouped_by_value.py
Component Count: | 126
Collated Components:
Item | Qty | Reference(s) | Value |  | LibPart | Footprint | Datasheet | DNP
1 | 13 | C1, C2, C3, C4, C5, C6, C7, C8, C9, C11, C12, C14, C16 | 0.1u |  | main board-eagle-import:C-EU050-025X075 | main board:C050-025X075
2 | 2 | C10, C13 | 22u |  | main board-eagle-import:CPOL-EUE2.5-5 | main board:E2,5-5
3 | 1 | C15 | 1u |  | main board-eagle-import:CPOL-EUE2.5-5 | main board:E2,5-5
4 | 14 | D1, D2, D3, D4, D5, D6, D7, D8, D11, D12, D13, D14, D15, D16 | BAT42 |  | main board-eagle-import:BAT42 | main board:DO35-7
5 | 2 | D9, D17 | 1N4148DO35-7 |  | main board-eagle-import:1N4148DO35-7 | main board:DO35-7
6 | 2 | D10, D18 | 1N5817 | Could be BAT42s as well | main board-eagle-import:SCHOTTKY-DIODEDO35-7 | main board:DO35-7
7 | 2 | H1, H2 | MountingHole_Pad |  | Mechanical:MountingHole_Pad | MountingHole:MountingHole_3.2mm_M3_DIN965_Pad_TopBottom | ~
8 | 4 | IC1, IC2, IC4, IC8 | TL084P |  | main board-eagle-import:TL084P | main board:DIL14
9 | 2 | IC3, IC6 | CD4081 |  | 4xxx:4081 | Package_DIP:DIP-14_W7.62mm_Socket_LongPads | http://www.intersil.com/content/dam/Intersil/documents/cd40/cd4073bms-81bms-82bms.pdf
10 | 1 | IC5 | MCP9422 |  | main board-eagle-import:MCP9422 | main board:DIL14
11 | 1 | IC7 | 78L05 |  | main board-eagle-import:78LXX | main board:78LXX
12 | 2 | JP1, JP5 | PINHD-1X18 | 1*18 Male 0.1 inch Header | main board-eagle-import:PINHD-1X18 | main board:1X18
13 | 1 | JP2 | PINHD-1X8 | 1*8 Male 0.1 inch header | main board-eagle-import:PINHD-1X8 | main board:1X08
14 | 1 | JP3 | PINHD-1X3 | 1*3 Male 0.1 inch Header | main board-eagle-import:PINHD-1X3 | main board:1X03
15 | 1 | JP4 | PINHD-2X8 | 2*8 Male 0.1 inch Male Header | main board-eagle-import:PINHD-2X8 | main board:2X08
16 | 4 | Q1, Q2, Q3, Q4 | BC546 |  | main board-eagle-import:BC546 | main board:TO92-EBC
17 | 24 | R1, R2, R3, R13, R19, R20, R21, R22, R23, R24, R25, R26, R36, R38, R41, R42, R49, R50, R51, R59, R66, R67, R68, R69 | 10K |  | main board-eagle-import:R-EU_0204/7 | main board:0204_7
18 | 10 | R4, R5, R7, R17, R18, R57, R58, R61, R62, R63 | 10k |  | main board-eagle-import:R-EU_0204/7 | main board:0204_7
19 | 1 | R6 | 1k |  | main board-eagle-import:R-EU_0204/7 | main board:0204_7
20 | 7 | R8, R31, R37, R43, R44, R45, R64 | 100k |  | main board-eagle-import:R-EU_0204/7 | main board:0204_7
21 | 4 | R9, R10, R11, R12 | 470 |  | main board-eagle-import:R-EU_0204/7 | main board:0204_7
22 | 6 | R14, R16, R53, R54, R55, R56 | 1M |  | main board-eagle-import:R-EU_0204/7 | main board:0204_7
23 | 2 | R15, R65 | 470R |  | main board-eagle-import:R-EU_0204/7 | main board:0204_7
24 | 1 | R27 | 220k |  | main board-eagle-import:R-EU_0204/7 | main board:0204_7
25 | 1 | R28 | 47k |  | main board-eagle-import:R-EU_0204/7 | main board:0204_7
26 | 2 | R29, R46 | 11k |  | main board-eagle-import:R-EU_0204/7 | main board:0204_7
27 | 1 | R30 | 3k3 |  | main board-eagle-import:R-EU_0204/7 | main board:0204_7
28 | 2 | R32, R39 | 22k |  | main board-eagle-import:R-EU_0204/7 | main board:0204_7
29 | 1 | R33 | 5k6 |  | main board-eagle-import:R-EU_0204/7 | main board:0204_7
30 | 2 | R34, R40 | 1k5 |  | main board-eagle-import:R-EU_0204/7 | main board:0204_7
31 | 3 | R35, R47, R48 | 100 |  | main board-eagle-import:R-EU_0204/7 | main board:0204_7
32 | 2 | R52, R60 | 10 |  | main board-eagle-import:R-EU_0204/7 | main board:0204_7
33 | 2 | TR1, TR2 | 1k | This is a min value - I used 10k Trimmers | main board-eagle-import:TRIM_EU-B64Y | main board:B64Y
34 | 1 | U$1 | ARDUINO_NANO |  | main board-eagle-import:ARDUINO_NANOARDUINO_NANO | main board:ARDUINO_NANO
35 | 1 | X1 | Power Header | 2*10 0.1 inch walled Header | main board-eagle-import:2510- | main board:PAK100_2500-10

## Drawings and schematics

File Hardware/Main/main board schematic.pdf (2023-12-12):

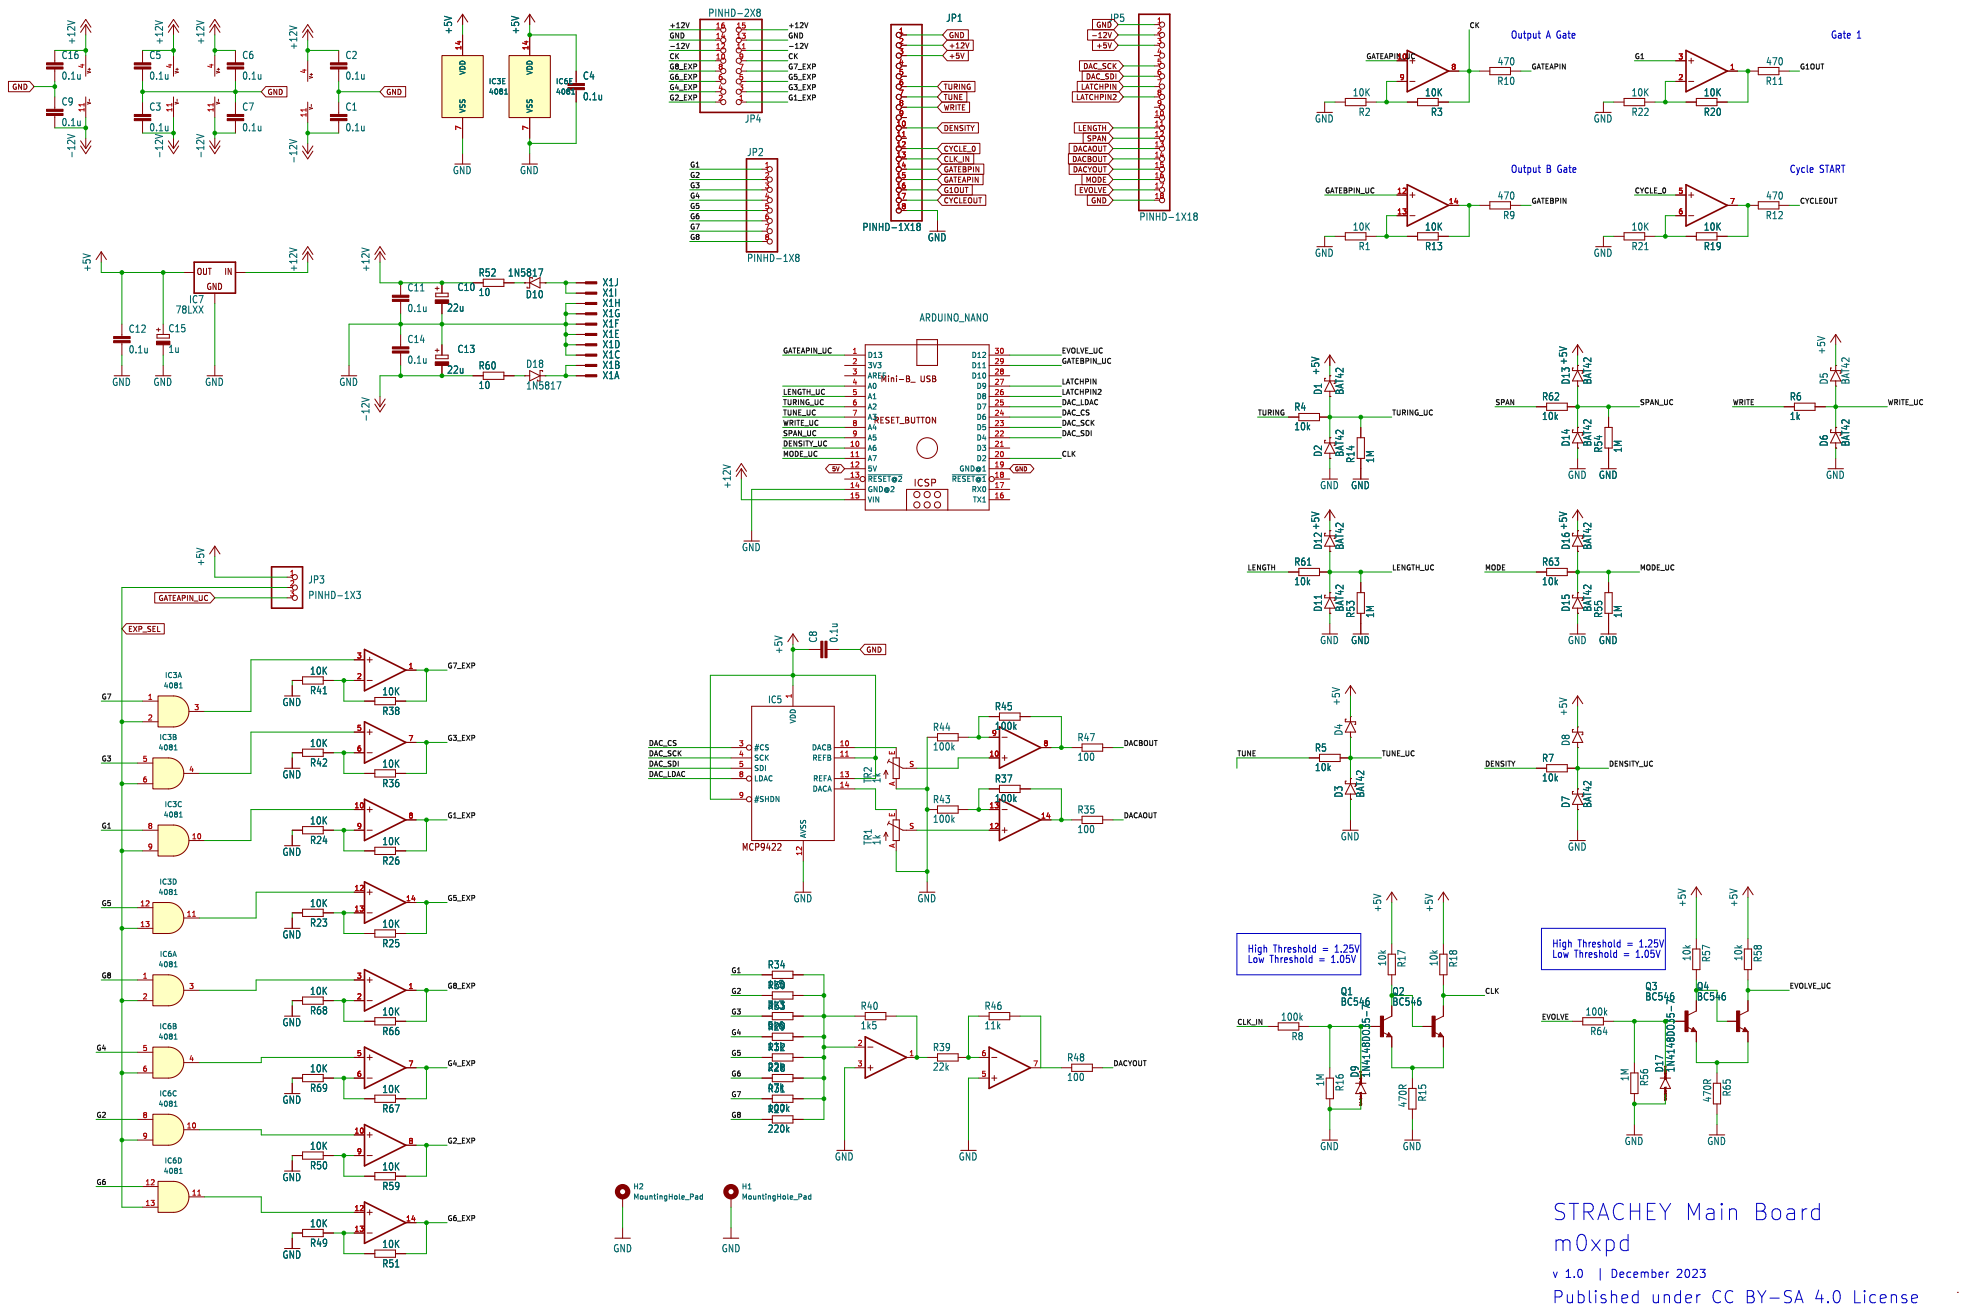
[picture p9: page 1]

EVOLVE DACAOUT DACYOUT DACBOUT MODE GND

Published under CC BY-SA 4.0 License

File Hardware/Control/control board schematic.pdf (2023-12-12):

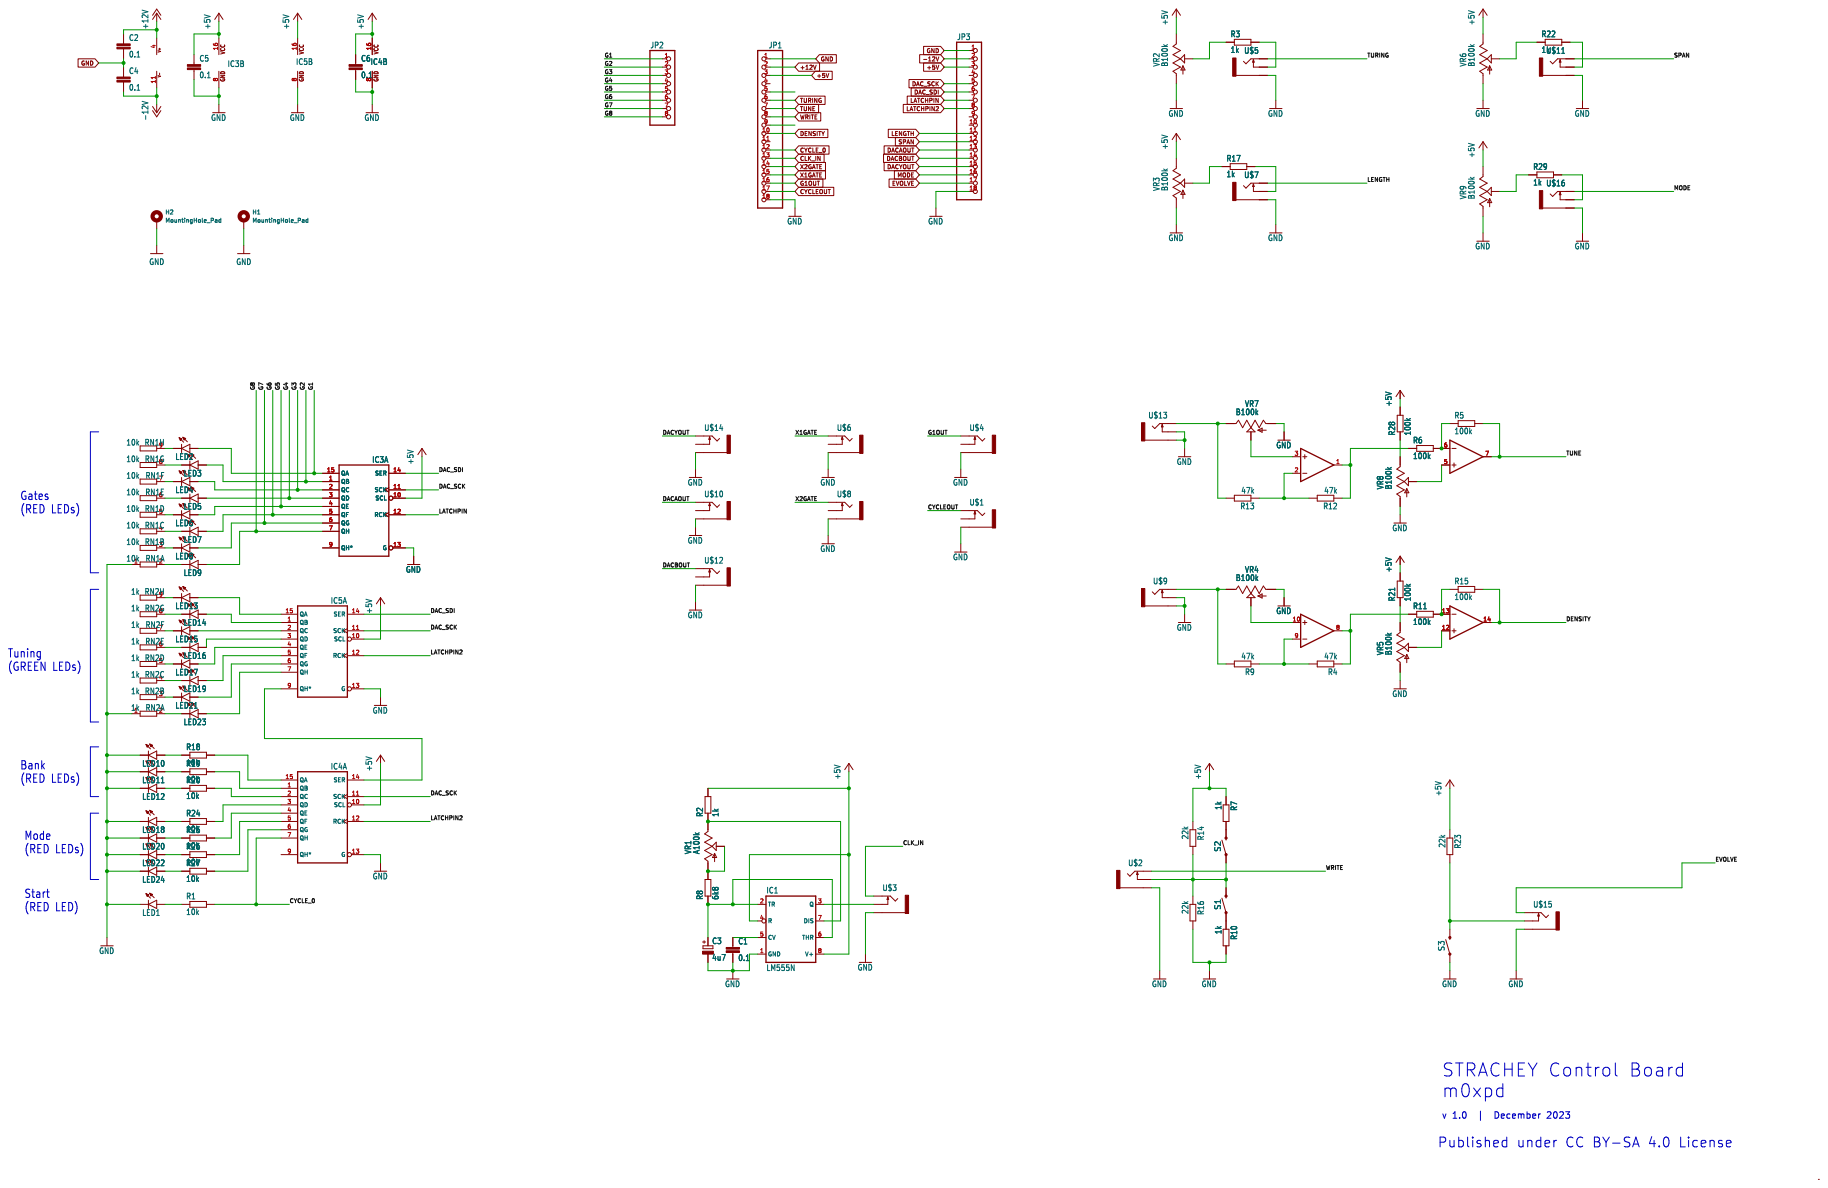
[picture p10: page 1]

Published under CC BY-SA 4.0 License

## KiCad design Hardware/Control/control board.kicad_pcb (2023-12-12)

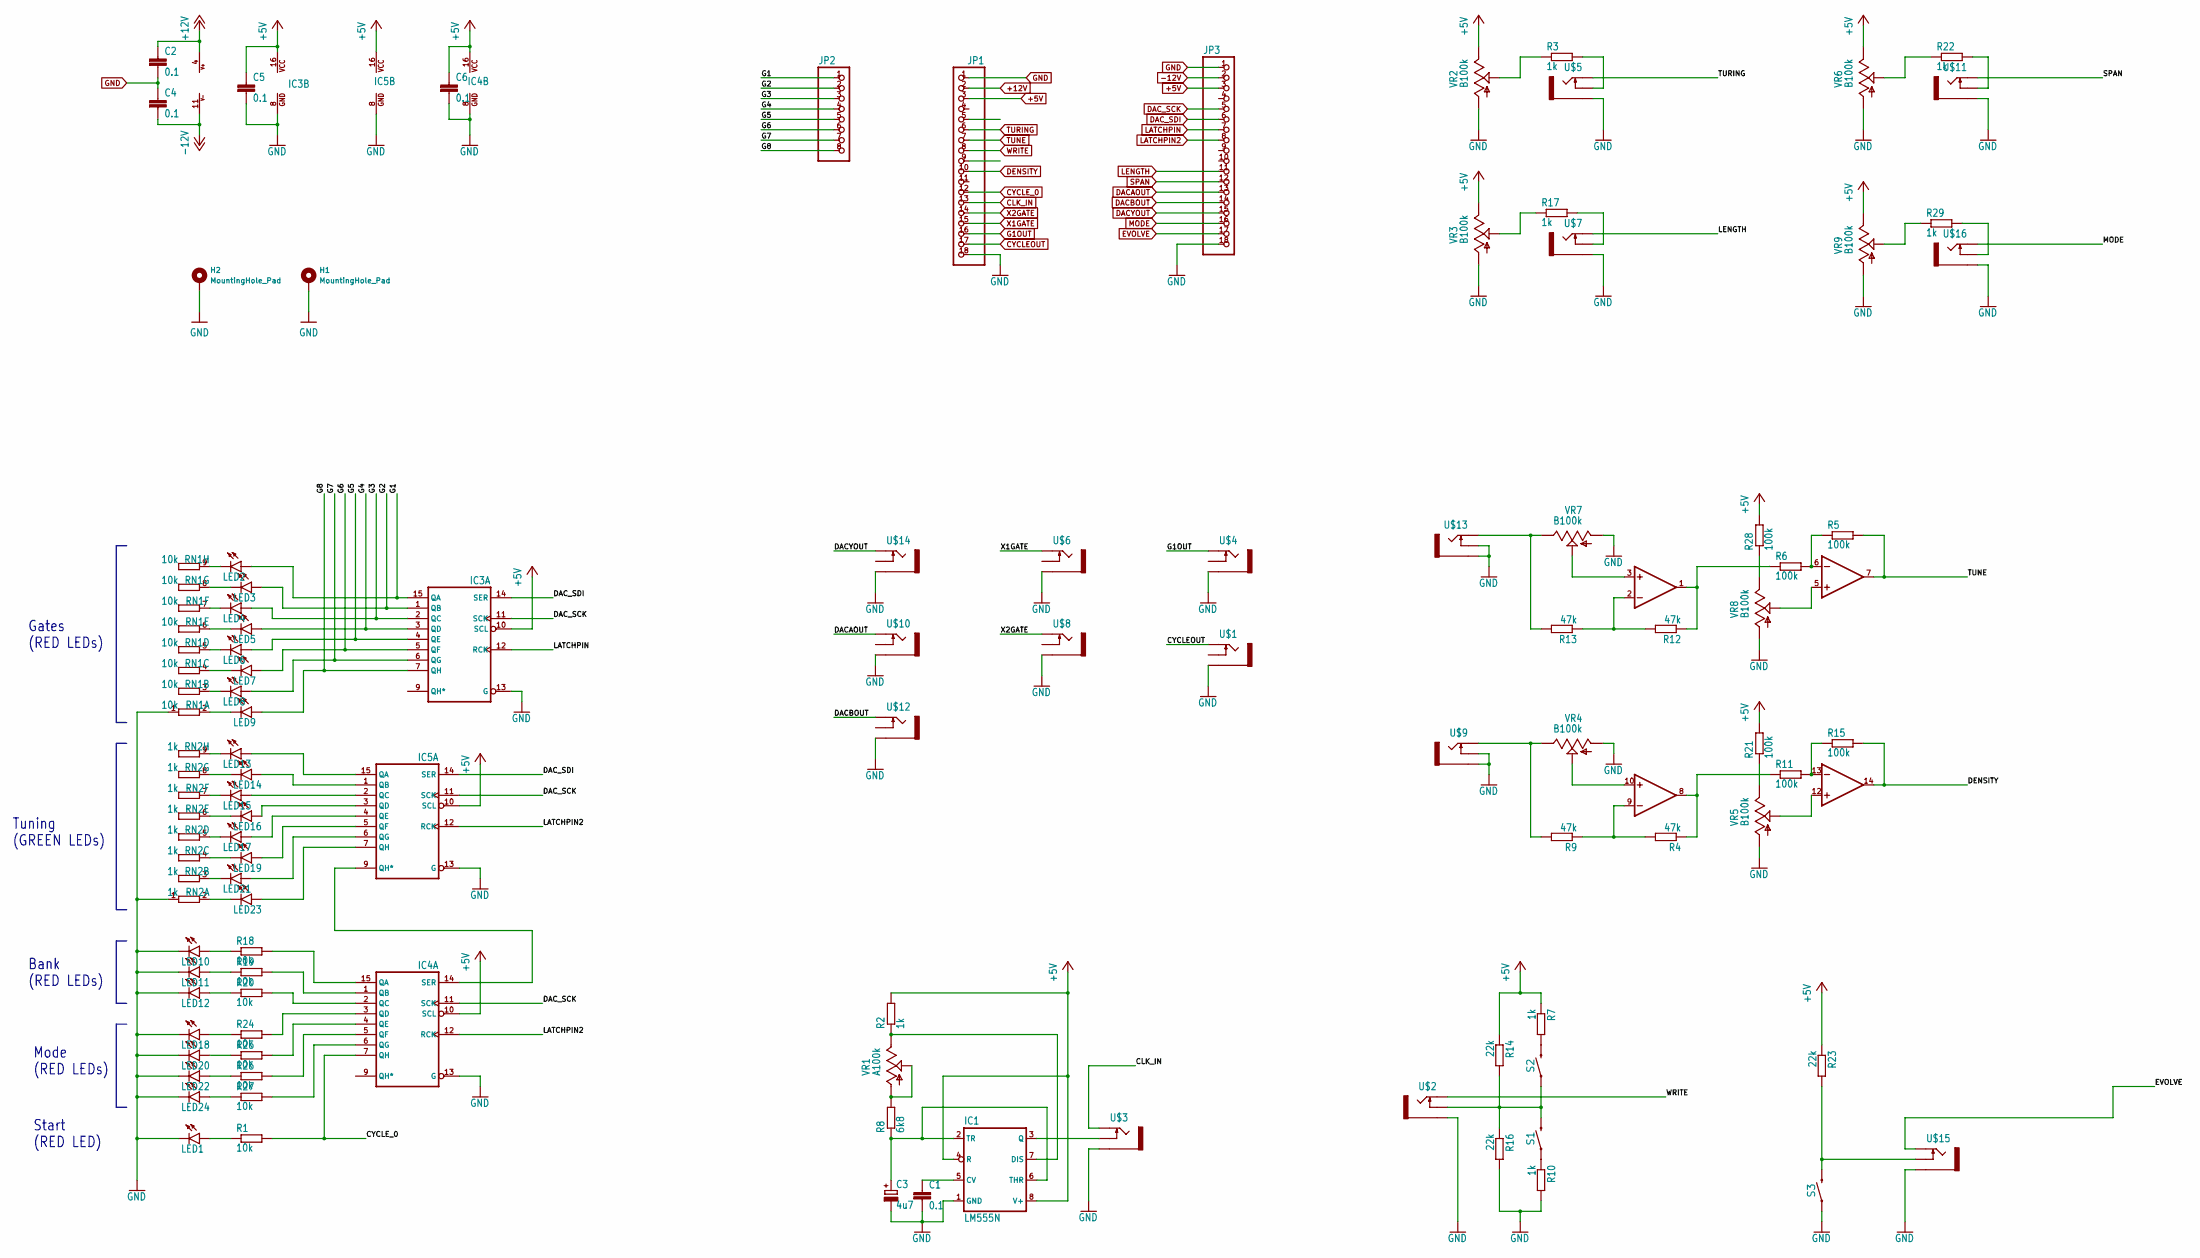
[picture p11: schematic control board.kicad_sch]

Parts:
C1, C2, C4, C5, C6: 0.1; C050-025X075
C3: 4u7; E2,5-5
H1, H2: MountingHole_Pad; MountingHole_3.2mm_M3_DIN965_Pad_TopBottom
IC1: LM555N; DIL08
IC2: TL084P; DIL14
IC3, IC4, IC5: 74HC595N; DIL16
JP1, JP3: 1X18
JP2: 1X08
LED1, LED2, LED3, LED4, LED5, LED6, LED7, LED8, LED9, LED10, LED11, LED12, LED13, LED14, LED15, LED16, LED17, LED18, LED19, LED20, LED21, LED22, LED23, LED24: LED3MM
R1, R18, R19, R20, R24, R25, R26, R27: 10k; 0204_7
R2, R3, R7, R10, R17, R22, R29: 1k; 0204_7
R4, R9, R12, R13: 47k; 0204_7
R5, R6, R11, R15, R21, R28: 100k; 0204_7
R8: 6k8; 0204_7
R14, R16, R23: 22k; 0204_7
RN1: 10k; SIL9
RN2: 1k; SIL9
S1, S2, S3: MOMENTARY-SWITCH-SPST-PTH-6.0MM; TACTILE_SWITCH_PTH_6.0MM
U$1, U$2, U$3, U$4, U$5, U$6, U$7, U$8, U$9, U$10, U$11, U$12, U$13, U$14, U$15, U$16: THONKICONN_JACK; WQP-PJ301M-12_JACK
VR1: A100k; 9MM_SNAP-IN_POT
VR2, VR3, VR4, VR5, VR6, VR7, VR8, VR9: B100k; 9MM_SNAP-IN_POT

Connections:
+5V: C5.1, C6.1, IC1.4 (R), IC1.8 (V+), IC3.10 (SCL), IC3.16 (VCC), IC4.10 (SCL), IC4.16 (VCC), IC5.10 (SCL), IC5.16 (VCC), JP1.3, JP3.3, R2.2, R7.1, R14.1, R21.2, R23.1, R28.2, VR2.3 (E), VR3.3 (E), VR6.3 (E), VR9.3 (E)
+12V: C2.1, IC2.4 (V+), JP1.2
-12V: C4.2, IC2.11 (V-), JP3.2
/G1: IC3.15 (QA), JP2.1, LED2.A
/G2: IC3.1 (QB), JP2.2, LED3.A
/G3: IC3.2 (QC), JP2.3, LED4.A
/G4: IC3.3 (QD), JP2.4, LED5.A
/G5: IC3.4 (QE), JP2.5, LED6.A
/G6: IC3.5 (QF), JP2.6, LED7.A
/G7: IC3.6 (QG), JP2.7, LED8.A
/G8: IC3.7 (QH), JP2.8, LED9.A
CLK_IN: JP1.13, U$3.P$1_TIP (TIP)
CYCLEOUT: JP1.17, U$1.P$1_TIP (TIP)
CYCLE_0: IC4.7 (QH), JP1.12, R1.2
DACAOUT: JP3.13, U$10.P$1_TIP (TIP)
DACBOUT: JP3.14, U$12.P$1_TIP (TIP)
DACYOUT: JP3.15, U$14.P$1_TIP (TIP)
DAC_SCK: IC3.11 (SCK), IC4.11 (SCK), IC5.11 (SCK), JP3.5
DAC_SDI: IC3.14 (SER), IC5.14 (SER), JP3.6
DENSITY: IC2.14 (OUT), JP1.10, R15.2
EVOLVE: JP3.17, U$15.P$1_TIP (TIP)
G1OUT: JP1.16, U$4.P$1_TIP (TIP)
GND: C1.2, C2.2, C3.-, C4.1, C5.2, C6.2, H1.1, H2.1, IC1.1 (GND), IC3.8 (GND), IC3.13 (G), IC4.8 (GND), IC4.13 (G), IC5.8 (GND), IC5.13 (G), JP1.1, JP1.18, JP3.1, JP3.18, LED1.K (C), LED10.K (C), LED11.K (C), LED12.K (C), LED18.K (C), LED20.K (C), LED22.K (C), LED24.K (C), R10.2, R16.2, RN1.1, RN2.1, S3.1, U$1.P$3_SLEEVE (SLEEVE), U$2.P$3_SLEEVE (SLEEVE), U$3.P$3_SLEEVE (SLEEVE), U$4.P$3_SLEEVE (SLEEVE), U$5.P$3_SLEEVE (SLEEVE), U$6.P$3_SLEEVE (SLEEVE), U$7.P$3_SLEEVE (SLEEVE), U$8.P$3_SLEEVE (SLEEVE), U$9.P$2_SWITCH (SWITCH), U$9.P$3_SLEEVE (SLEEVE), U$10.P$3_SLEEVE (SLEEVE), U$11.P$3_SLEEVE (SLEEVE), U$12.P$3_SLEEVE (SLEEVE), U$13.P$2_SWITCH (SWITCH), U$13.P$3_SLEEVE (SLEEVE), U$14.P$3_SLEEVE (SLEEVE), U$15.P$3_SLEEVE (SLEEVE), U$16.P$3_SLEEVE (SLEEVE), VR2.1 (A), VR3.1 (A), VR4.1 (A), VR5.1 (A), VR6.1 (A), VR7.1 (A), VR8.1 (A), VR9.1 (A)
LATCHPIN: IC3.12 (RCK), JP3.7
LATCHPIN2: IC4.12 (RCK), IC5.12 (RCK), JP3.8
LENGTH: JP3.11, U$7.P$1_TIP (TIP)
MODE: JP3.16, U$16.P$1_TIP (TIP)
unnamed: IC5.15 (QA), LED13.A
unnamed: IC5.1 (QB), LED14.A
unnamed: IC5.2 (QC), LED15.A
unnamed: IC5.3 (QD), LED16.A
unnamed: IC5.4 (QE), LED17.A
unnamed: IC5.5 (QF), LED19.A
unnamed: IC5.6 (QG), LED21.A
unnamed: IC5.7 (QH), LED23.A
unnamed: IC4.14 (SER), IC5.9 (QH*)
unnamed: IC4.15 (QA), R18.2
unnamed: IC4.1 (QB), R19.2
unnamed: IC4.2 (QC), R20.2
unnamed: IC4.3 (QD), R24.2
unnamed: IC4.4 (QE), R25.2
unnamed: IC4.5 (QF), R26.2
unnamed: IC4.6 (QG), R27.2
unnamed: C1.1, IC1.5 (CV)
unnamed: IC1.7 (DIS), R2.1, VR1.3 (E)
unnamed: IC1.3 (Q), U$3.P$2_SWITCH (SWITCH)
unnamed: C3.+, IC1.2 (TR), IC1.6 (THR), R8.1
unnamed: IC2.3 (+IN), VR7.2 (S)
unnamed: IC2.2 (-IN), R12.2, R13.1
unnamed: IC2.1 (OUT), R6.1, R12.1
unnamed: IC2.5 (+IN), VR8.2 (S)
unnamed: IC2.6 (-IN), R5.1, R6.2
unnamed: IC2.10 (+IN), VR4.2 (S)
unnamed: IC2.9 (-IN), R4.2, R9.1
unnamed: IC2.8 (OUT), R4.1, R11.1
unnamed: IC2.12 (+IN), VR5.2 (S)
unnamed: IC2.13 (-IN), R11.2, R15.1
unnamed: LED2.K (C), RN1.9 (2)
unnamed: LED3.K (C), RN1.8 (2)
unnamed: LED4.K (C), RN1.7 (2)
unnamed: LED5.K (C), RN1.6 (2)
unnamed: LED6.K (C), RN1.5 (2)
unnamed: LED7.K (C), RN1.4 (2)
unnamed: LED8.K (C), RN1.3 (2)
unnamed: LED9.K (C), RN1.2
unnamed: LED13.K (C), RN2.9 (2)
unnamed: LED14.K (C), RN2.8 (2)
unnamed: LED15.K (C), RN2.7 (2)
unnamed: LED16.K (C), RN2.6 (2)
unnamed: LED17.K (C), RN2.5 (2)
unnamed: LED19.K (C), RN2.4 (2)
unnamed: LED21.K (C), RN2.3 (2)
unnamed: LED23.K (C), RN2.2
unnamed: LED10.A, R18.1
unnamed: LED11.A, R19.1
unnamed: LED12.A, R20.1
unnamed: LED18.A, R24.1
unnamed: LED20.A, R25.1
unnamed: LED22.A, R26.1
unnamed: LED24.A, R27.1
unnamed: LED1.A, R1.1
unnamed: R10.1, S1.1
unnamed: R7.2, S2.3 (2)
unnamed: R14.2, R16.1, S1.3 (2), S2.1, U$2.P$2_SWITCH (SWITCH)
unnamed: R23.2, S3.3 (2), U$15.P$2_SWITCH (SWITCH)
unnamed: R3.2, U$5.P$2_SWITCH (SWITCH)
unnamed: R17.2, U$7.P$2_SWITCH (SWITCH)
unnamed: R22.2, U$11.P$2_SWITCH (SWITCH)
unnamed: R13.2, U$13.P$1_TIP (TIP), VR7.3 (E)
unnamed: R9.2, U$9.P$1_TIP (TIP), VR4.3 (E)
unnamed: R29.2, U$16.P$2_SWITCH (SWITCH)
unnamed: R8.2, VR1.1 (A), VR1.2 (S)
unnamed: R3.1, VR2.2 (S)
unnamed: R17.1, VR3.2 (S)
unnamed: R22.1, VR6.2 (S)
unnamed: R28.1, VR8.3 (E)
unnamed: R21.1, VR5.3 (E)
unnamed: R29.1, VR9.2 (S)
SPAN: JP3.12, U$11.P$1_TIP (TIP)
TUNE: IC2.7 (OUT), JP1.7, R5.2
TURING: JP1.6, U$5.P$1_TIP (TIP)
WRITE: JP1.8, U$2.P$1_TIP (TIP)
X1GATE: JP1.15, U$6.P$1_TIP (TIP)
X2GATE: JP1.14, U$8.P$1_TIP (TIP)

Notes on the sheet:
Tuning (GREEN LEDs)
Bank (RED LEDs)
Start (RED LED)
Mode (RED LEDs)
Gates (RED LEDs)

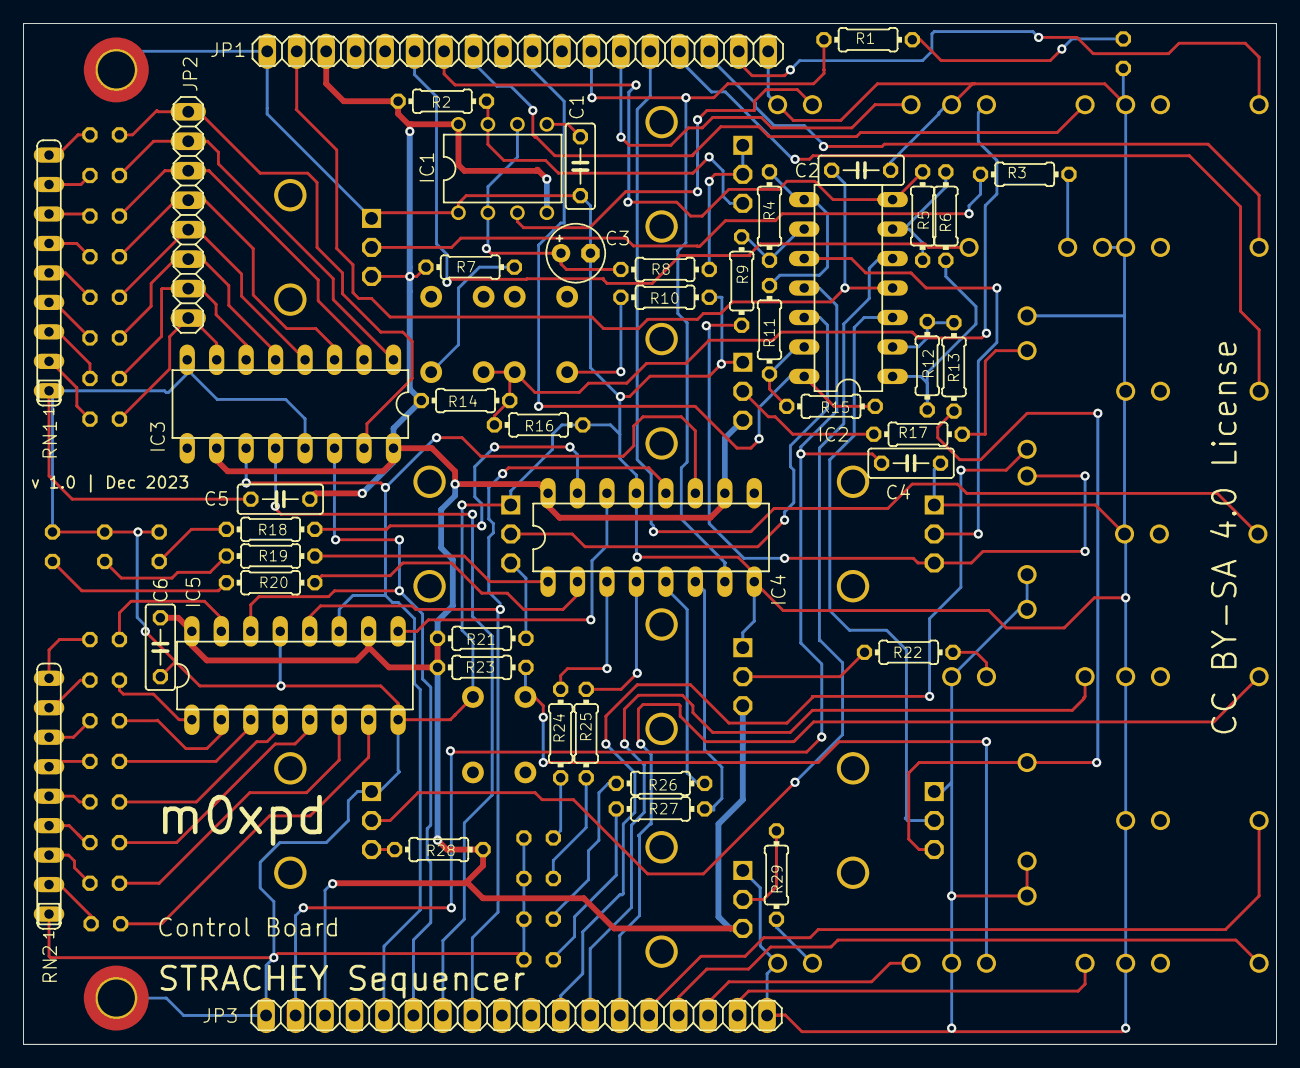
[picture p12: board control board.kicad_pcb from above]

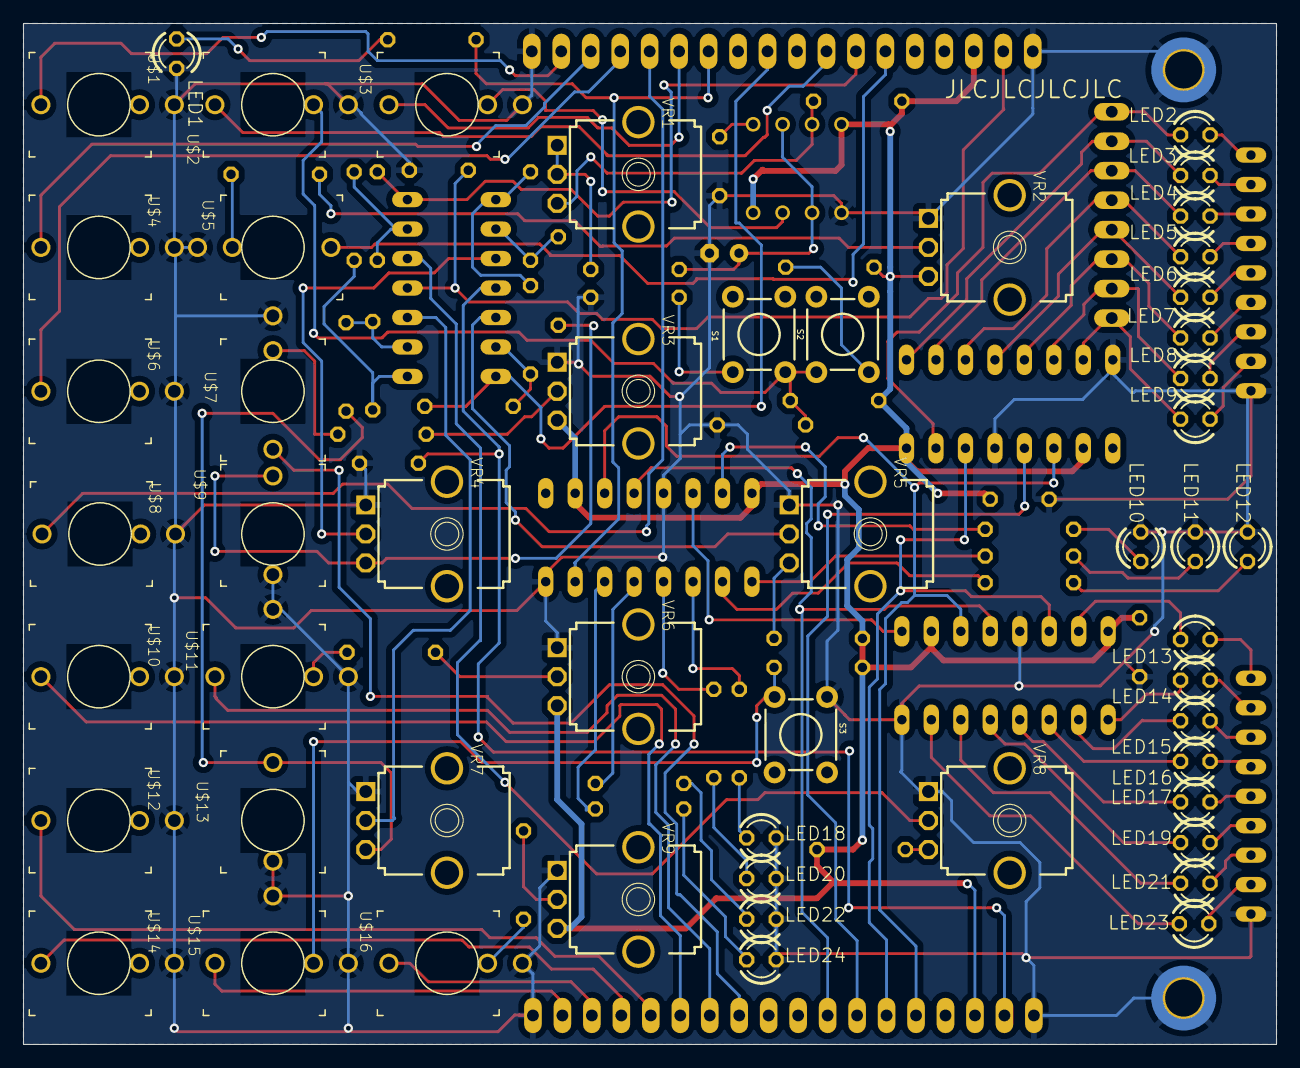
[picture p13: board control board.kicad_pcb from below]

Board: 2 copper layers, 108.0 x 88.0 mm, 99 parts (52 on the bottom side), 104 nets.

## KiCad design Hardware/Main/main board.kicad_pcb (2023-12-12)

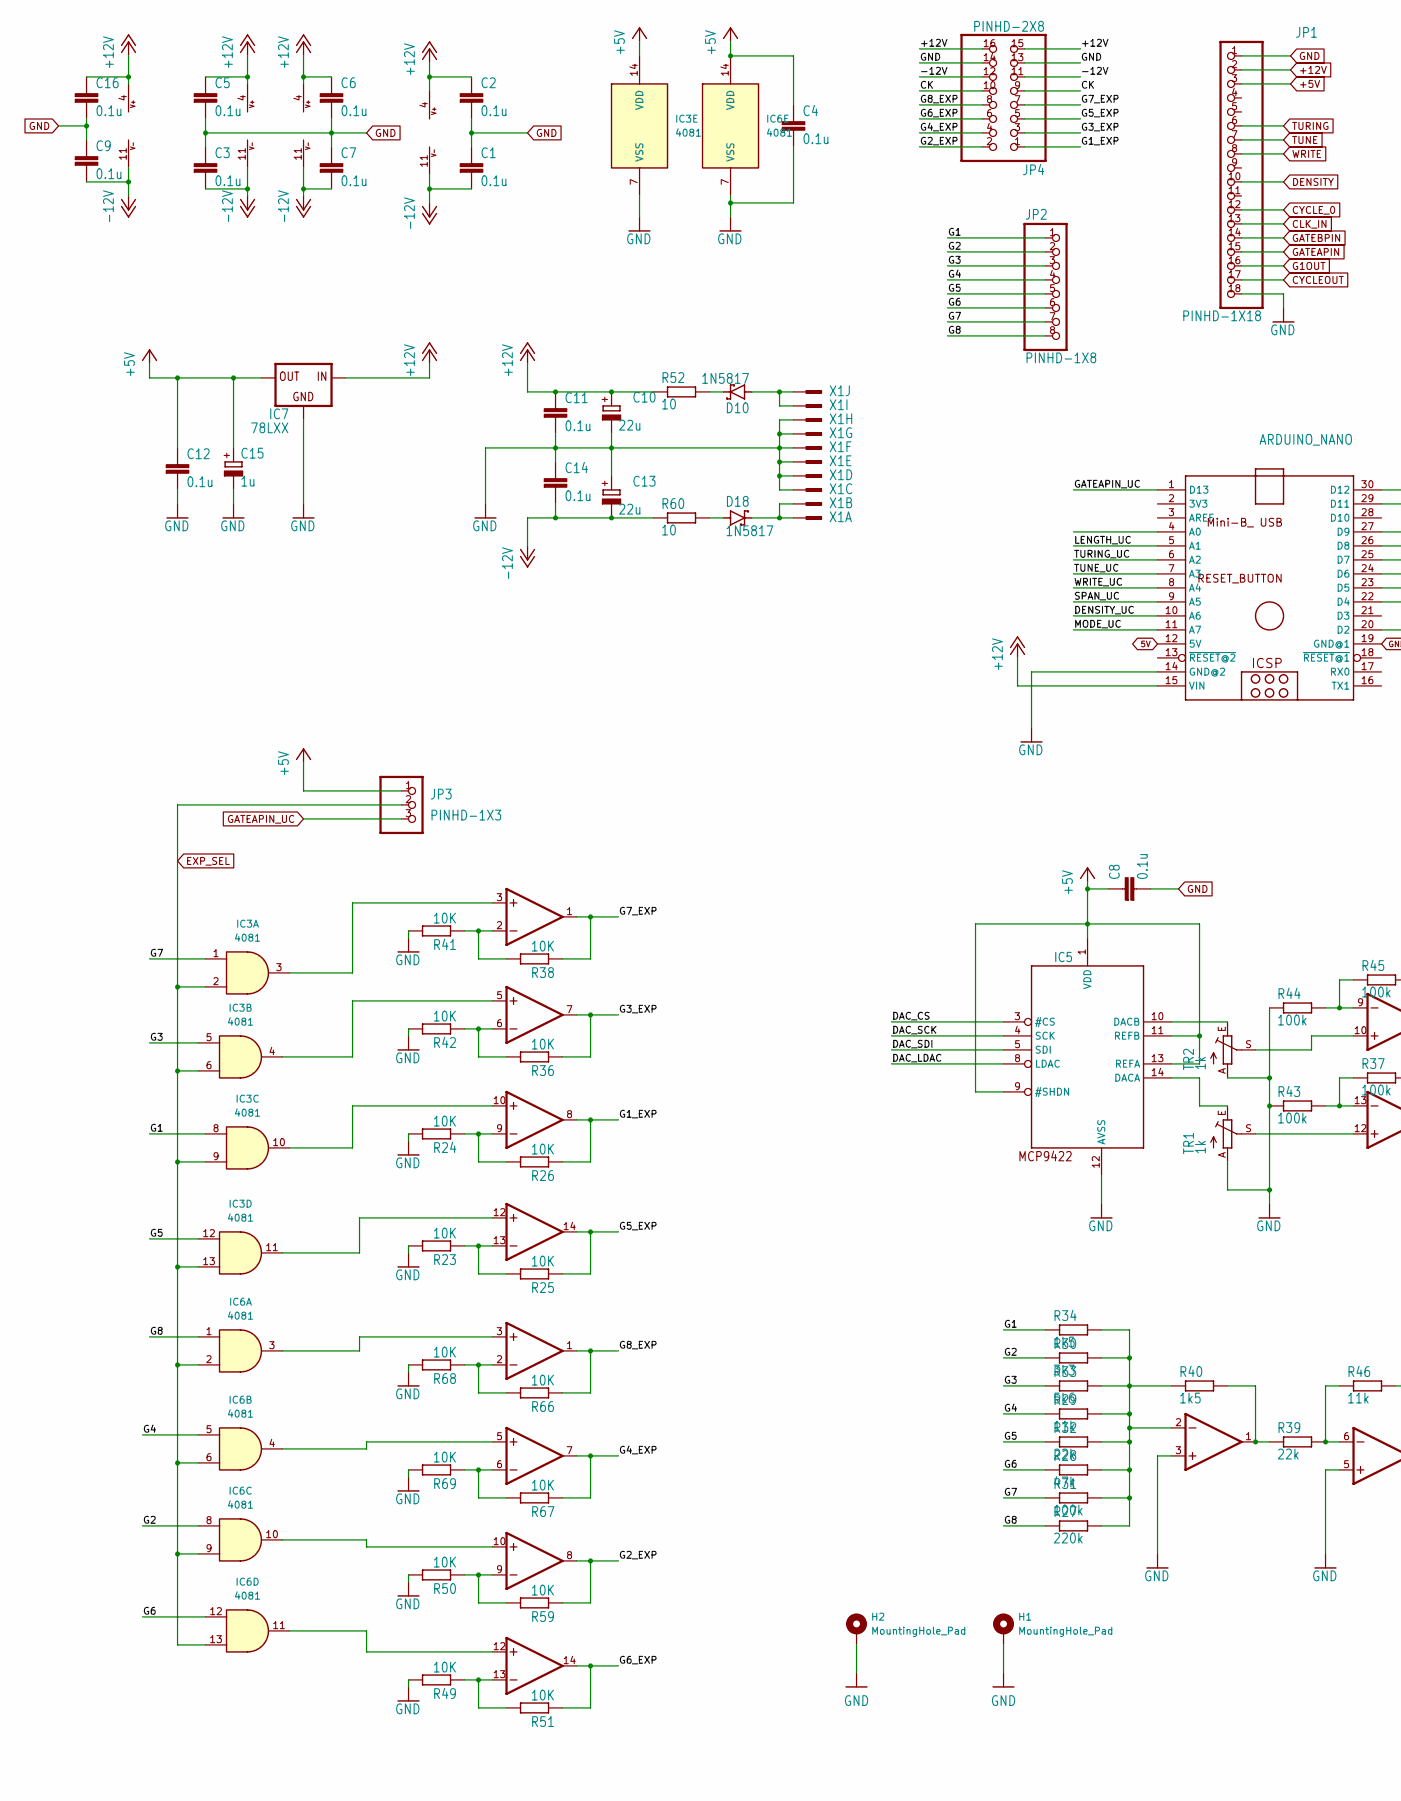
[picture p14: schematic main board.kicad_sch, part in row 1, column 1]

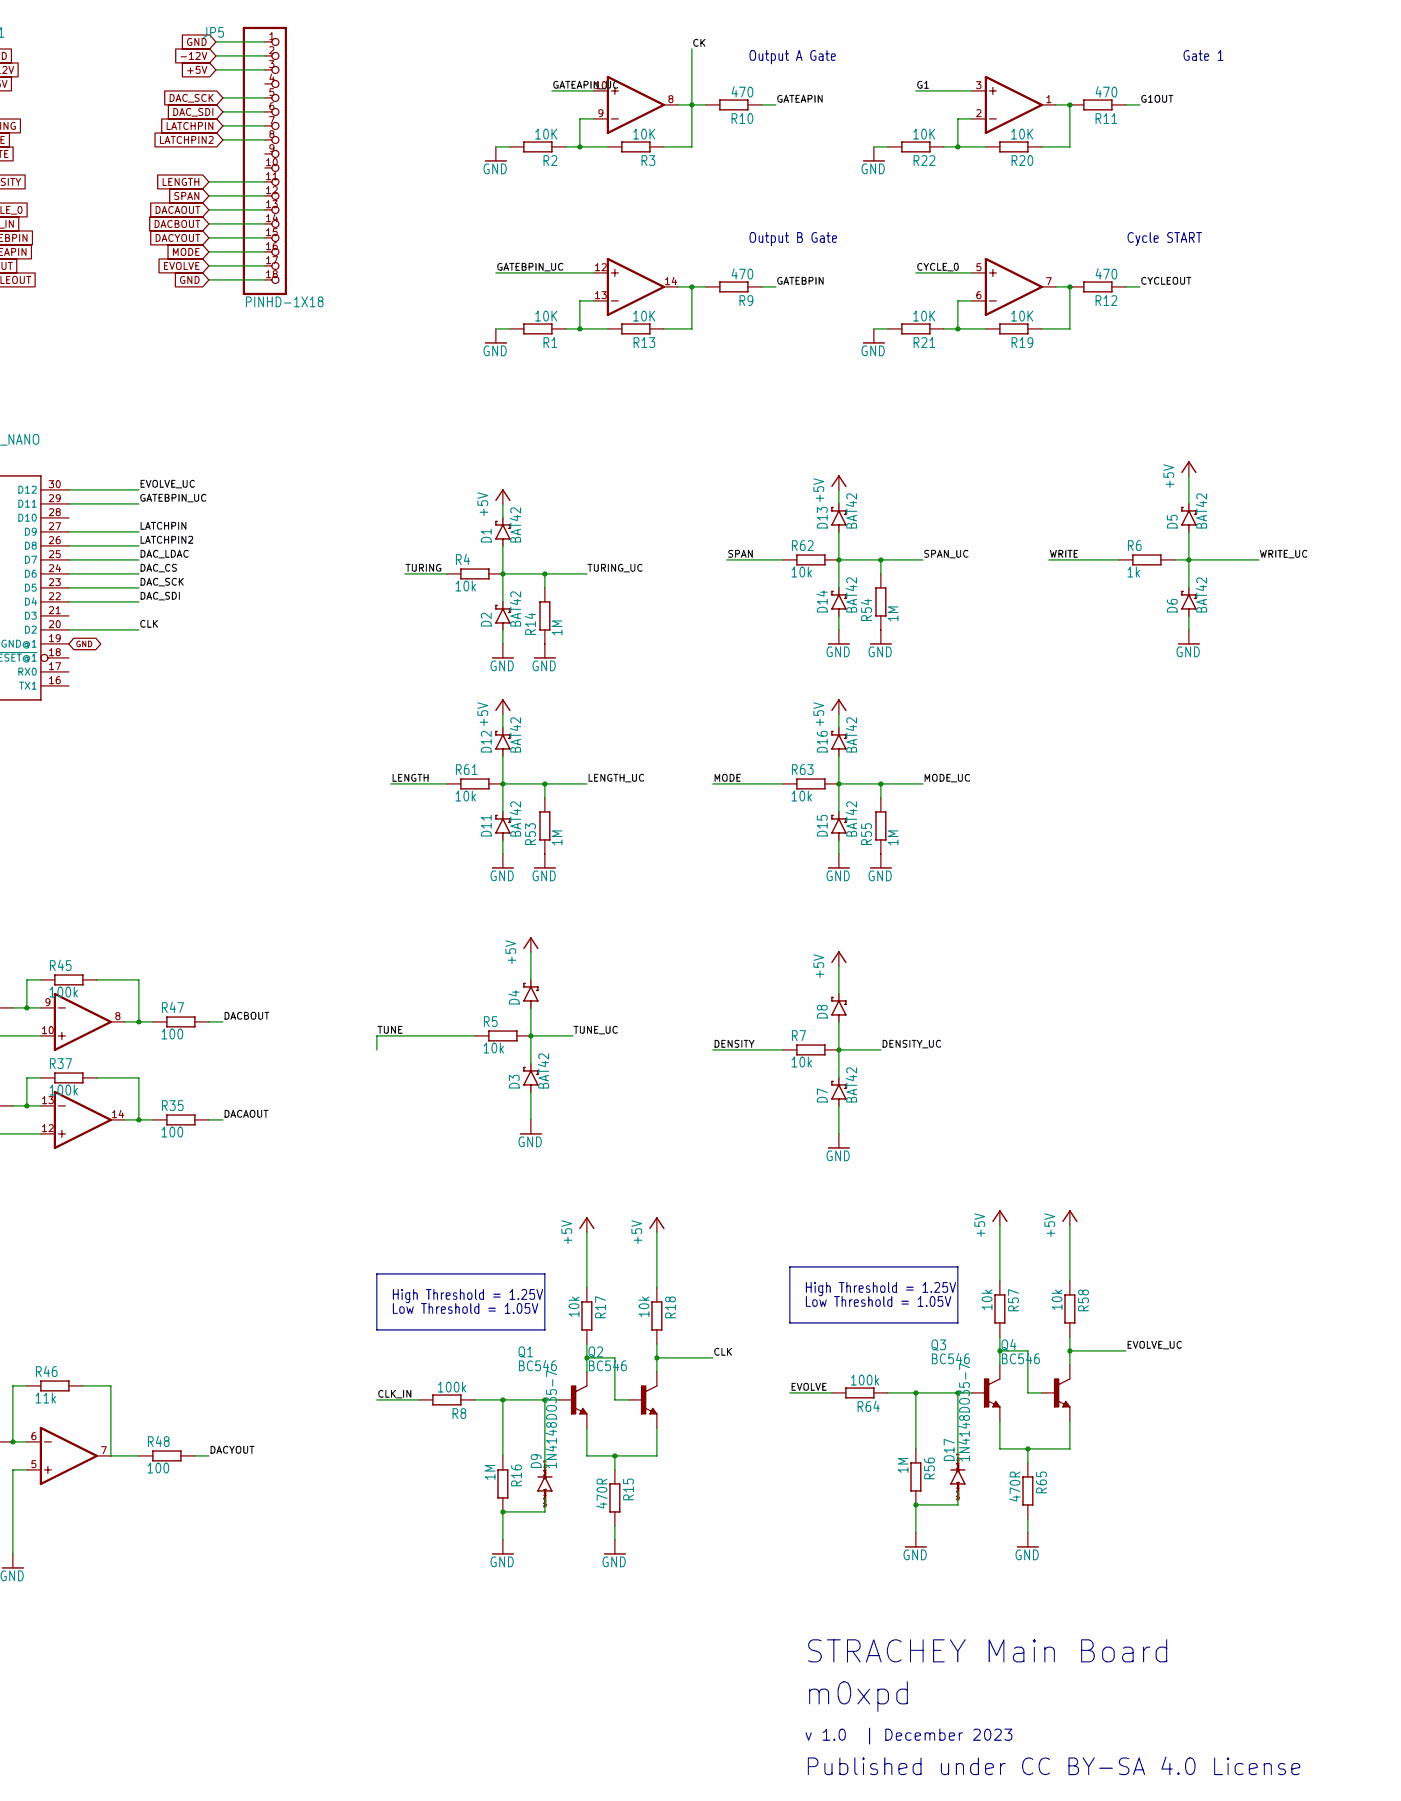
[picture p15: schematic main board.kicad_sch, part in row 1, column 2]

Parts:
C1, C2, C3, C4, C5, C6, C7, C8, C9, C11, C12, C14, C16: 0.1u; C050-025X075
C10, C13: 22u; E2,5-5
C15: 1u; E2,5-5
D1, D2, D3, D4, D5, D6, D7, D8, D11, D12, D13, D14, D15, D16: BAT42; DO35-7
D9, D17: 1N4148DO35-7; DO35-7
D10, D18: 1N5817; DO35-7
H1, H2: MountingHole_Pad; MountingHole_3.2mm_M3_DIN965_Pad_TopBottom
IC1, IC2, IC4, IC8: TL084P; DIL14
IC3, IC6: 4081; DIP-14_W7.62mm_Socket_LongPads
IC5: MCP9422; DIL14
IC7: 78LXX
JP1, JP5: PINHD-1X18; 1X18
JP2: PINHD-1X8; 1X08
JP3: PINHD-1X3; 1X03
JP4: PINHD-2X8; 2X08
Q1, Q2, Q3, Q4: BC546; TO92-EBC
R1, R2, R3, R13, R19, R20, R21, R22, R23, R24, R25, R26, R36, R38, R41, R42, R49, R50, R51, R59, R66, R67, R68, R69: 10K; 0204_7
R4, R5, R7, R17, R18, R57, R58, R61, R62, R63: 10k; 0204_7
R6: 1k; 0204_7
R8, R31, R37, R43, R44, R45, R64: 100k; 0204_7
R9, R10, R11, R12: 470; 0204_7
R14, R16, R53, R54, R55, R56: 1M; 0204_7
R15, R65: 470R; 0204_7
R27: 220k; 0204_7
R28: 47k; 0204_7
R29, R46: 11k; 0204_7
R30: 3k3; 0204_7
R32, R39: 22k; 0204_7
R33: 5k6; 0204_7
R34, R40: 1k5; 0204_7
R35, R47, R48: 100; 0204_7
R52, R60: 10; 0204_7
TR1, TR2: 1k; B64Y
U$1: ARDUINO_NANO
X1: 2510-; PAK100_2500-10

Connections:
5V: U$1.12 (5V)
+5V: C4.1, C8.1, C12.1, C15.+, D1.C, D4.C, D5.C, D8.C, D12.C, D13.C, D16.C, IC3.14 (VDD), IC5.1 (VDD), IC5.9 (#SHDN), IC5.11 (REFB), IC5.13 (REFA), IC6.14 (VDD), IC7.OUT, JP1.3, JP3.1, JP5.3, R17.1, R18.1, R57.1, R58.1
+12V: C2.1, C5.1, C6.1, C10.+, C11.1, C16.1, IC1.4 (V+), IC2.4 (V+), IC4.4 (V+), IC7.IN, IC8.4 (V+), JP1.2, JP4.15, JP4.16, R52.1, U$1.15 (VIN)
-12V: C1.2, C3.2, C7.2, C9.2, C13.-, C14.2, IC1.11 (V-), IC2.11 (V-), IC4.11 (V-), IC8.11 (V-), JP4.11, JP4.12, JP5.2, R60.1
/CK: IC1.8 (OUT), JP4.9, JP4.10, R3.1, R10.2
/CLK: Q2.C, R18.2, U$1.20 (D2)
/DAC_CS: IC5.3 (#CS), U$1.24 (D6)
/DAC_LDAC: IC5.8 (LDAC), U$1.25 (D7)
/DENSITY_UC: D7.C, D8.A, R7.2, U$1.10 (A6)
/EVOLVE_UC: Q4.C, R58.2, U$1.30 (D12)
/G1: IC1.3 (+IN), IC3.8, JP2.1, R34.1
/G1_EXP: IC2.8 (OUT), JP4.1, R26.1
/G2: IC6.8, JP2.2, R30.1
/G2_EXP: IC8.8 (OUT), JP4.2, R59.1
/G3: IC3.5, JP2.3, R33.1
/G3_EXP: IC2.7 (OUT), JP4.3, R36.1
/G4: IC6.5, JP2.4, R29.1
/G4_EXP: IC8.7 (OUT), JP4.4, R67.1
/G5: IC3.12, JP2.5, R32.1
/G5_EXP: IC2.14 (OUT), JP4.5, R25.1
/G6: IC6.12, JP2.6, R28.1
/G6_EXP: IC8.14 (OUT), JP4.6, R51.1
/G7: IC3.1, JP2.7, R31.1
/G7_EXP: IC2.1 (OUT), JP4.7, R38.1
/G8: IC6.1, JP2.8, R27.1
/G8_EXP: IC8.1 (OUT), JP4.8, R66.1
/GATEBPIN_UC: IC1.12 (+IN), U$1.29 (D11)
/LENGTH_UC: D11.C, D12.A, R53.2, R61.2, U$1.5 (A1)
/MODE_UC: D15.C, D16.A, R55.2, R63.2, U$1.11 (A7)
/SPAN_UC: D13.A, D14.C, R54.2, R62.2, U$1.9 (A5)
/TUNE_UC: D3.C, D4.A, R5.2, U$1.7 (A3)
/TURING_UC: D1.A, D2.C, R4.2, R14.2, U$1.6 (A2)
/WRITE_UC: D5.A, D6.C, R6.2, U$1.8 (A4)
CLK_IN: JP1.13, R8.2
CYCLEOUT: JP1.17, R12.1
CYCLE_0: IC1.5 (+IN), JP1.12
DACAOUT: JP5.13, R35.2
DACBOUT: JP5.14, R47.2
DACYOUT: JP5.15, R48.2
DAC_SCK: IC5.4 (SCK), JP5.5, U$1.23 (D5)
DAC_SDI: IC5.5 (SDI), JP5.6, U$1.22 (D4)
DENSITY: JP1.10, R7.1
EVOLVE: JP5.17, R64.2
EXP_SEL: IC3.2, IC3.6, IC3.9, IC3.13, IC6.2, IC6.6, IC6.9, IC6.13, JP3.2
G1OUT: JP1.16, R11.1
GATEAPIN: JP1.15, R10.1
GATEAPIN_UC: IC1.10 (+IN), JP3.3, U$1.1 (D13)
GATEBPIN: JP1.14, R9.1
GND: C1.1, C2.2, C3.1, C4.2, C5.2, C6.2, C7.1, C8.2, C9.1, C10.-, C11.2, C12.2, C13.+, C14.1, C15.-, C16.2, D2.A, D3.A, D6.A, D7.A, D9.A, D11.A, D14.A, D15.A, D17.A, H1.1, H2.1, IC3.7 (VSS), IC4.3 (+IN), IC4.5 (+IN), IC5.12 (AVSS), IC6.7 (VSS), IC7.GND, JP1.1, JP1.18, JP4.13, JP4.14, JP5.1, JP5.18, R1.2, R2.2, R14.1, R15.2, R16.2, R21.2, R22.2, R23.2, R24.2, R41.2, R42.2, R43.1, R44.1, R49.2, R50.2, R53.1, R54.1, R55.1, R56.2, R65.2, R68.2, R69.2, TR1.A, TR2.A, U$1.14 (GND@2), U$1.19 (GND@1), X1.3 (KL), X1.4 (KL), X1.5 (KL), X1.6 (KL), X1.7 (KL), X1.8 (KL)
LATCHPIN: JP5.7, U$1.27 (D9)
LATCHPIN2: JP5.8, U$1.26 (D8)
LENGTH: JP5.11, R61.1
MODE: JP5.16, R63.1
unnamed: D9.C, Q1.B, R8.1, R16.1
unnamed: D17.C, Q3.B, R56.1, R64.1
unnamed: D10.C, R52.2
unnamed: D18.A, R60.2
unnamed: IC6.3, IC8.3 (+IN)
unnamed: IC8.2 (-IN), R66.2, R68.1
unnamed: IC6.4, IC8.5 (+IN)
unnamed: IC8.6 (-IN), R67.2, R69.1
unnamed: IC6.10, IC8.10 (+IN)
unnamed: IC8.9 (-IN), R50.1, R59.2
unnamed: IC6.11, IC8.12 (+IN)
unnamed: IC8.13 (-IN), R49.1, R51.2
unnamed: IC5.14 (DACA), TR1.E
unnamed: IC5.10 (DACB), TR2.E
unnamed: IC4.2 (-IN), R27.2, R28.2, R29.2, R30.2, R31.2, R32.2, R33.2, R34.2, R40.1
unnamed: IC4.1 (OUT), R39.1, R40.2
unnamed: IC4.6 (-IN), R39.2, R46.1
unnamed: IC4.7 (OUT), R46.2, R48.1
unnamed: IC4.10 (+IN), TR2.S
unnamed: IC4.9 (-IN), R44.2, R45.1
unnamed: IC4.8 (OUT), R45.2, R47.1
unnamed: IC4.12 (+IN), TR1.S
unnamed: IC4.13 (-IN), R37.1, R43.2
unnamed: IC4.14 (OUT), R35.1, R37.2
unnamed: IC2.3 (+IN), IC3.3
unnamed: IC2.2 (-IN), R38.2, R41.1
unnamed: IC2.5 (+IN), IC3.4
unnamed: IC2.6 (-IN), R36.2, R42.1
unnamed: IC2.10 (+IN), IC3.10
unnamed: IC2.9 (-IN), R24.1, R26.2
unnamed: IC2.12 (+IN), IC3.11
unnamed: IC2.13 (-IN), R23.1, R25.2
unnamed: IC1.2 (-IN), R20.2, R22.1
unnamed: IC1.1 (OUT), R11.2, R20.1
unnamed: IC1.6 (-IN), R19.2, R21.1
unnamed: IC1.7 (OUT), R12.2, R19.1
unnamed: IC1.9 (-IN), R2.1, R3.2
unnamed: IC1.13 (-IN), R1.1, R13.2
unnamed: IC1.14 (OUT), R9.2, R13.1
unnamed: Q1.C, Q2.B, R17.2
unnamed: Q1.E, Q2.E, R15.1
unnamed: Q3.C, Q4.B, R57.2
unnamed: Q3.E, Q4.E, R65.1
unnamed: D18.C, X1.1 (KL), X1.2 (KL)
unnamed: D10.A, X1.9 (KL), X1.10 (KL)
SPAN: JP5.12, R62.1
TUNE: JP1.7, R5.1
TURING: JP1.6, R4.1
WRITE: JP1.8, R6.1

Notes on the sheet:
v 1.0 | December 2023
Gate 1
m0xpd
STRACHEY Main Board
Published under CC BY-SA 4.0 License
Low Threshold = 1.05V
High Threshold = 1.25V
Output B Gate
Output A Gate
Cycle START

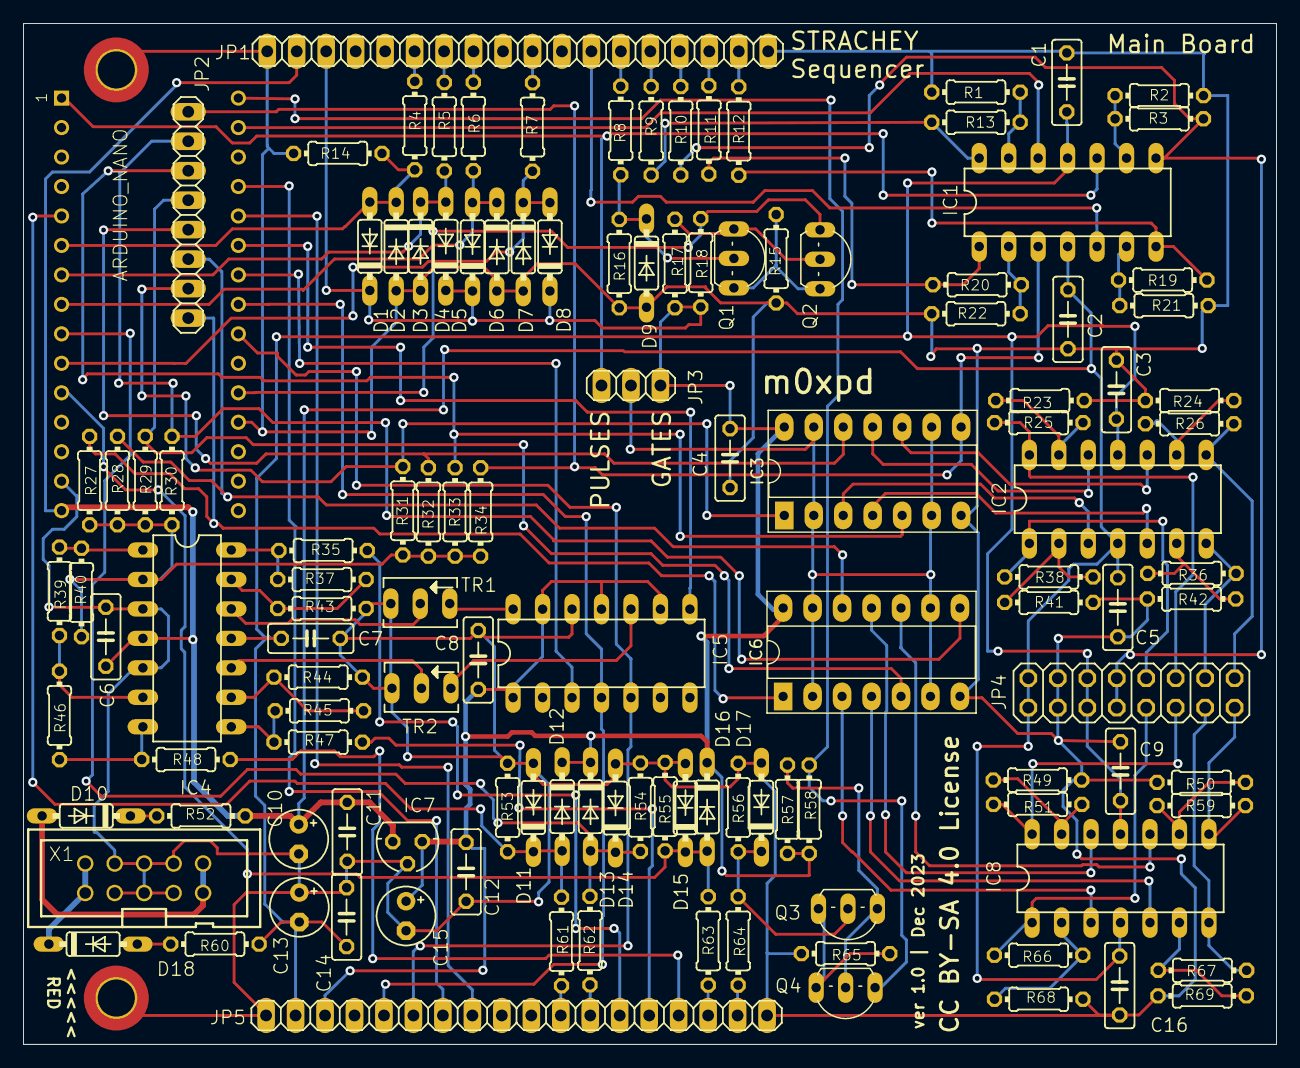
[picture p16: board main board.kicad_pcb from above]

Board: 2 copper layers, 108.0 x 88.0 mm, 126 parts (0 on the bottom side), 101 nets.

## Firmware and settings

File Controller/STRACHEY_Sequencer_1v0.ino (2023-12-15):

//
// Control Code for the STRACHEY Sequencer
//
// A Random Looping Sequencer, 
// named for Christopher Strachey
// https://en.wikipedia.org/wiki/Christopher_Strachey
//
// details at https://github.com/m0xpd/STRACHEY
//
//
// The STRACHEY sequencer implements the Tuning Strategy for  Klee-type Sequencers:
// https://github.com/m0xpd/TuningStrategyForVoltages
// and includes a new software implementation of the Turing Machine, an 
// open-source (CC BY-SA) design from Music Thing Modular. 
//
// STRACHEY incorporates Euclidean Rhythm generation, which was derived from:
// http://clsound.com/euclideansequenc.html
// itself derived from Tom Whitwell's code, available at:
// https://www.modwiggler.com/forum/viewtopic.php?p=607737#p607737
//
// version 1v0
//
// Paul Darlington
// m0xpd
// 10 December 2023
//
// This code published under Creative Commons CC BY-SA 4.0 License
// -----------------------------------------------------------------
// for Arduino NANO

int seqLength = 8;
int seqStep = 0;
byte upper_byte = 0x10;
byte lower_byte = 0;
const int StepsPerSemitone = 51;          
uint16_t euclidPattern;

//---------------------------------------------------------------------------------------------------|----------------------|
// Here are the tunings             Description                                                      |.. Tuning Strategy #..|
int weights[24][8] = {
  //                                                                                                 |                      |
  //                            Bank A - Basic Tunings                                               |                      |
  //                                                                                                 |                      |
  {0, 0, 7, 0, 0, 0, 0, 0},    // 0  Root and Fifth                                                  |         (3)          |
  {0, 0, 3, 0, 2, 0, 5, 0},    // 1  AEOLIAN - "Natural Minor"                                       |         14           |
  {0, 0, 7, 0, 3, 0, 0, 0},    // 2  Minor 7th                                                       |          5           |
  {0, 0, 7, 4, 0, 0, 0, 0},    // 3  Major 7th                                                       |          6           |
  {0, 0, 6, 0, 3, 0, 0, 0},    // 4  Dim 7                                                           |          8           | 
  {0, 0, 8, 0, 4, 0, 0, 0},    // 5  Augmented                                                       |          7           |
  {0, 0, 10, 7, 0, 0, 0, 0},   // 6  "Sus 7th" feel                                                  |         10           |
  {0, 0, 10, 0, 0, 4, 0, 0},   // 7  "9th Feel"                                                      |          0           |
  //-------------------------------------------------------------------------------------------------|--------------------- | 
  //                            Bank B - Modes etc                                                   |                      |
  //                                                                                                 |                      |
  {0, 0, 7, 0, 0, 0, 0, 0},    // 8  Root and Fifth                                                  |         (3)          |
  {0, 0, 3, 0, 2, 0, 5, 0},    // 9  AEOLIAN - "Natural Minor"                                       |         14           |
  {0, 0, 2, 0, 7, 0, 3, 0},    // 10 DORIAN                                                          |         11           |
  {0, 0, 7, 10, 5, 0, 2, 0},   // 11 PHRYGIAN                                                        |         13           |
  {0, 0, 2, 2, 0, 7, 5, 0},    // 12 IONIAN - Major (may alias as DORIAN through PDF)                |         18           |
  {0, 0, 2, 5, 7, 0, 7, 0},    // 13 Hexatonic Scale, close to Major but with no 7th degree          |         22           |
  {0, 0, 2, 5, 0, 4, 0, 0},    // 14 Octatonic Scale - Major Scale with added flat 5                 |         20           |
  {0, 0, 10, 7, 0, 2, 0, 0},   // 15 Hexatonic Scale with no third                                   |         23           |
  //-------------------------------------------------------------------------------------------------|----------------------|
  //                            Band C - Symmetric Scales etc                                        |                      |
  //                                                                                                 |                      |
  {0, 0, 12, 0, 0, 0, 0, 0},   // 16 Root and Octave                                                 |         (3)          |
  {0, 0, 6, 0, 6, 0, 0, 0},    // 17 Tritone                                                         |        (15)          |
  {0, 0, 8, 0, 4, 0, 0, 0},    // 18 Augmented                                                       |          7           |
  {0, 0, 6, 0, 3, 0, 0, 0},    // 19 diminished                                                      |          8           |
  {0, 0, 2, 0, 6, 0, 4, 0},    // 20 Whole-tone                                                      |         16           |
  {0, 0, 2, 1, 6, 0, 4, 0},    // 21 Chromatic Scale                                                 |         17           |
  {0, 0, 2, 5, 7, 7, 7, 0},    // 22 Major Scale (may alias as Dorian through PDF)                   |         19           |       
  {12, 11, 9, 7, 5, 4, 2, 0}   // 23 Descending Major Scale                                          |        N/A           |
};
//--------------------------------------------------------------------------------------------------------------------------|

int wA[8] = {0, 0, 0, 0, 0, 0, 0, 0};
int wB[8] = {0, 0, 0, 0, 0, 0, 0, 0};
int gates[16] = {1, 0, 0, 0, 0, 0, 0, 0, 0, 0, 0, 0, 0, 0, 0, 0};
int gatecarry = 0;
int gateDisplay = 0;
int semitoneA = 0;
int semitoneB = 0;
int Offset = 0;
int Density = 0;
int oldDensity = 0;
int Turing = 0;   // Main Turing Control Knob Value
int TuringCurve = 0; // non-linear operation on the Turing Input
int Tune = 0;     // Slider Tuning
int oldTune = 0;  // Previous Slider Tuning
int Write = 0;    // Write Switch value
int Span = 0;     // Octave Span value;
int oldSpan = 0;  // old value of Span;
int oldseqLength = 0;
int TuneDisplay = 0;
int TuneDisplay2 = 0;
int lowTune = 0;
int highTune = 0;
int highTuneDisplay = 0;
int stroke = 1;

// Arduino pin allocations...
const int CLK_IN = 2;
const int  DAC_SDI = 4;         // MCP4922...
const int  DAC_SCK = 5;
const int  DAC_CS = 6;
const int  DAC_LDAC = 7;
const int latchPin2 = 8;        //Pin connected to SH_CP of second 74HC595 (pin 12)
const int latchPin = 9;         //Pin connected to SH_CP of 74HC595 (pin 12)
const int gateBPin = 11;
const int modePin = 12;          // INPUT for CHANGE call inputs
const int gateAPin = 13;

const int LengthKnob = 1;        // ANALOG INPUT for LENGTH Control
const int TuringKnob = 2;        // ANALOG INPUT for main TURING Machine Control
const int TuneKnob = 3;          // ANALOG INPUT for Weights TUNING Selection
const int WriteSwitch = 4;       // ANALOG INPUT for Write Switch Input
const int SpanKnob = 5;          // ANALOG INPUT for Octave SPAN input
const int DensityKnob = 6;       // ANALOG INPUT for Euclidean DENSITY input
const int ModeKnob = 7;          // ANALOG INPUT for weight change 'METHOD' inputs


bool modeIn = true;              // input from modePin
bool ChangeFlag = false;         // Flag for Change call
int mode = 0;


int CycleNo = 0;                // Pointer within the CycleSequence

// This is the vector which gets permuted on CHANGE calls, according to selected METHODs:
int gateIndex[8] = {0, 1, 2, 3, 4, 5, 6, 7};  

void setup() {
  setupHardware();
  randomSeed(millis());
  gateDisplay = 0;
  digitalWrite(latchPin, LOW);
  shiftOut(DAC_SDI, DAC_SCK, MSBFIRST, gateDisplay);
  digitalWrite(latchPin, HIGH);
  write_Tune_Display();
  seqLength = 2 + (analogRead(LengthKnob) / 72);
  if (seqLength < 2) {
    seqLength = 2;
  }
  oldseqLength = seqLength;
  Density = floor((1024 - analogRead(DensityKnob)) * seqLength / 1024);
  euclidPattern = euclid(seqLength, seqLength - Density, 0);
}

void loop() {

  while (digitalRead(CLK_IN) == 0) {
    Turing = analogRead(TuringKnob);      // Read controls during clock low phase...
    Tune = (analogRead(TuneKnob)) / 41.5;
    Span = analogRead(SpanKnob) / 256;
    mode = analogRead(ModeKnob) / 63.5;
    modeIn = digitalRead(modePin);
    if (modeIn == 0) {                    // and check for change calls
      ChangeFlag = true;
    }
  }
                                 // Now we're at clock 'High" phase
  if (CycleNo == 0) {            // if it's the start of the pattern cycle, set the 'START' indication
    bitSet(TuneDisplay2, 7);
  }
  else {                          // otherwise, clear it
    bitClear(TuneDisplay2, 7);
  }

  modeIn = digitalRead(modePin);  // check for a CHANGE call
  if (modeIn == 0) {
    ChangeFlag = true;
  }

  write_Gate_Display();           // write the Gates
  write_Tune_Display();           // and other LEDs
                                  // and calculate the Turing update curve (a non-inear fn of the TURING control setting)...
  TuringCurve = floor(512.0 * (1.0 - cos((1.0 * Turing) * 3.1412 / 1024.0)));

  int newseqLength = 2 + (analogRead(LengthKnob) / 72);                 // Read LENGTH and
  Density = floor((1024 - analogRead(DensityKnob)) * seqLength / 1024); // DENSITY inputs and
  if (newseqLength != seqLength) {                                      // (if required)
    if (newseqLength < 2) {                                             // update...
      newseqLength = 2;
    }
    seqLength = newseqLength;
  }
  if (Density != oldDensity) {                                          // if Density has changed,
    oldDensity = Density;                                               // record the change
    euclidPattern = euclid(seqLength, seqLength - Density, 0);          // and re-calculate the Euclid pattern
  }

  if (Tune != oldTune) {                                                // if a new TUNING has been selected
    write_Tune_Display();                                               // update the display
    for (int i = 0; i < 8; i++) {                                       // and the weights
      wA[i] = weights[Tune][i];
      wB[i] = weights[Tune][i];
    }
    wB[0] = 0;
    wB[1] = 0;
    wB[7] = 0;
    oldTune = Tune;                                                     // and remember the change
 
  }
  if (Span != oldSpan) {                                                // if there has been a change on the SPAN input
    switch (Span) {                                                     // see what the new value is 
      case 0:                                                           // and change the (channel A) weight vector accordingly...
        wA[0] = 0;
        wA[1] = 0;
        wA[7] = 0;
        break;
      case 1:
        wA[0] = 12;
        wA[1] = 0;
        wA[7] = 0;
        break;
      case 2:
        wA[0] = 12;
        wA[1] = 12;
        wA[7] = 0;
        break;
      case 3:
        wA[0] = 12;
        wA[1] = 12;
        wA[7] = 12;
        break;
    }
    oldSpan = Span;                                                       // and remember the change
  }
  if (seqLength != oldseqLength) {                                        // if there's a change on the LENGTH input
    oldseqLength = seqLength;
    euclidPattern = euclid(seqLength, seqLength - Density, 0);            // re-calculate the Euclidean pattern for the new sequence Length
  }

  semitoneA = 0;                                      // clear the semitones, ready for the new values
  semitoneB = 0;
  int j = 0;
  for (int i = 0; i < 8; i++) {                       // and form the new scalar products
    j = gateIndex[i];                                 // of gates and weights
    semitoneA = semitoneA + gates[j] * wA[i];         // for channel A (INCLUDING THE PERMUTATION)
    semitoneB = semitoneB + gates[i] * wB[i];         // and channel B
  }
  
  Set_DAC_A(semitoneA * StepsPerSemitone);            // play the channel A output - set the DAC
  
  bool Bplay = bitRead(euclidPattern, CycleNo);       // Is there an onset in the Euclidean pattern at this point (Bplay=true)?
  if (Bplay) {                                        // do we have to play channel B on this step?
    Set_DAC_B(semitoneB * StepsPerSemitone);          // if yes, set the DAC channel
    digitalWrite(gateBPin, HIGH);
  }
  digitalWrite(gateAPin, HIGH);
  while (digitalRead(CLK_IN) == 1) {                  // wait until the end of the clock HIGH phase, reading the WRITE switch
    Write = analogRead(WriteSwitch);
  }
  modeIn = digitalRead(modePin);                      // then take one more last-ditch read of the CHANGE input
  if (modeIn == 0) {
    ChangeFlag = true;
  }

  digitalWrite(gateAPin, LOW);
  digitalWrite(gateBPin, LOW);
  // =============================================================================
  // This is the MAIN PART of the SOFTWARE IMPLEMENTATION OF THE TURING MACHINE...
  // ============================================================================= 
  // first, bump the gate vector...
  gatecarry = gates[seqLength - 1];
  for (int i = 15; i > 0; i = i - 1) {
    gates[i] = gates[i - 1];
  }
  // then set gate[0], and get two random variables ready...
  byte randgate = random(0, 2); // a random boolean (0 or 1)
  int decide = random(1, 511);  // and a random integer (1:510)
  // check the value read from the write switch...
  if (Write > 900) {    // here Write was HIGH, so we are writing ones into gate 0
    gates[0] = 1;
  }
  else if (Write < 100) { // here Write was low, so we are writing zeros into gate 0
    gates[0] = 0;
  }
  else {                // here the Write swich was inactive, and the update proceeds according to the setting of the TURING control
    if (Turing >= 512) { // Here, we're in the right-hand side of the TURING control
      if (decide < 1024 - TuringCurve) { // compare the random variable 'decide' with 1024-Turing Curve ; if it's smaller 
        gates[0] = randgate;             // randomise gate 0
      }
      else {                             // otherwise,
        gates[0] = (gatecarry);          // feedback the bit from the selected point in the shift register into gate 0
      }
    }
    else {              // Here, we're in the left-hand side of the TURING control
      if (decide < TuringCurve) {    // compare the random variable 'decide' with Turing Curve ; if it's smaller 
        gates[0] = randgate;         // randomise gate 0
      }
      else {                         // otherwise,
        gates[0] = not(gatecarry);   // feedback the complement of the bit from the selected point in the shift register into gate 0
      }
    }
  }

  CycleNo = CycleNo + 1;          // maintain a count of the Cycle 
  if (CycleNo >= seqLength) {     // in mod LENGTH
    CycleNo = 0;                  // and if we're at 0...
    if (ChangeFlag == true) {     // work the CHANGE, if any is called...
      switch (mode) {
        case 0:
          gateIndexReset();
          ChangeFlag = false;
          break;
        case 1:
          gateIndexHighSort();
          ChangeFlag = false;
          break;
        case 2:
          gateIndexLowSort();
          ChangeFlag = false;
          break;         
        case 3:
          gateAscendingSingleSort();
          ChangeFlag = false;
          break;
        case 4:
         gateDescendingSingleSort();
          ChangeFlag = false;
          break;          
        case 5:
          gateRandomSingle();
          ChangeFlag = false;
          break;          
        case 6:
          PlainHunt();
          ChangeFlag = false;
          break;
        case 8:
          gateIndexRoR();
          ChangeFlag = false;
          break;
        case 9:
          gateIndexRoL();
          ChangeFlag = false;
          break;          
        case 12:
          gateIndexReverse();
          ChangeFlag = false;
          break;             
        case 13:
          gateIndexFlip();
          ChangeFlag = false;
          break;                             
        case 15:
          gateIndexShuffle();
          ChangeFlag = false;
          break;

        default:
          // catch all the other (up-populated) cases
          ChangeFlag = false;
          break;
      }
    }

  }
  if (ChangeFlag == true) {
    // flash the Method LEDs if a CHANGE has been called...
    write_Tune_Display_ModeOFF();
  }
  // end of loop
  // ----------------------------------------------------------------------------------------------------------
}


// just subroutines below here...

void write_Gate_Display() {
  // Display Gates on LEDs via a 74HC595 shift 
  gateDisplay = 0;
  for (int i = 0; i < 8; i++) {
    gateDisplay = gateDisplay + (gates[i] << i);
  }
  digitalWrite(latchPin, LOW);
  shiftOut(DAC_SDI, DAC_SCK, MSBFIRST, gateDisplay);
  digitalWrite(latchPin, HIGH);
}

void write_Tune_Display(){
  // Display TUNING and other status info on LEDs
  // via 2 74HC595 shifts 
  lowTune = Tune % 8;
  highTune = Tune / 8;
  highTuneDisplay = 0;

  switch (highTune) {
    case 0:
      highTuneDisplay = 0x1;
      break;
    case 1:
      highTuneDisplay = 0x2;
      break;
    case 2:
      highTuneDisplay = 0x4;
      break;
  }
  TuneDisplay = 1 << lowTune;

  int wTuneDisplay2 = TuneDisplay2 | mode << 3;
  wTuneDisplay2 = wTuneDisplay2 | highTuneDisplay;
  digitalWrite(latchPin2, LOW);
  shiftOut(DAC_SDI, DAC_SCK, MSBFIRST, wTuneDisplay2);
  shiftOut(DAC_SDI, DAC_SCK, MSBFIRST, TuneDisplay);
  digitalWrite(latchPin2, HIGH);
}

void write_Tune_Display_ModeOFF()
{
  // Turn off the mode/method LEDs to implement a FLASH...
  TuneDisplay = 1 << lowTune;
  int wTuneDisplay2 = TuneDisplay2 | (0) << 3;
  wTuneDisplay2 = wTuneDisplay2 | highTuneDisplay;
  digitalWrite(latchPin2, LOW);
  shiftOut(DAC_SDI, DAC_SCK, MSBFIRST, wTuneDisplay2);
  shiftOut(DAC_SDI, DAC_SCK, MSBFIRST, TuneDisplay);
  digitalWrite(latchPin2, HIGH);
}


void Set_DAC_A(int Input_Value) {
  // subroutine to set DAC channel A
  lower_byte = Input_Value & 0xff;
  upper_byte = (Input_Value >> 8) & 0x0f;
  bitSet(upper_byte, 4);
  bitSet(upper_byte, 5);
  digitalWrite(DAC_CS, LOW);
  shiftOut(DAC_SDI, DAC_SCK, MSBFIRST, (upper_byte));
  shiftOut(DAC_SDI, DAC_SCK, MSBFIRST, (lower_byte));
  digitalWrite(DAC_SDI, LOW);
  digitalWrite(DAC_CS, HIGH);
  digitalWrite(DAC_LDAC, LOW);
  digitalWrite(DAC_LDAC, HIGH);
}

void Set_DAC_B(int Input_Value) {
  // subroutine to set DAC channel B
  lower_byte = Input_Value & 0xff;
  upper_byte = (Input_Value >> 8) & 0x0f;
  bitSet(upper_byte, 4);
  bitSet(upper_byte, 5);
  bitSet(upper_byte, 7);
  digitalWrite(DAC_CS, LOW);
  shiftOut(DAC_SDI, DAC_SCK, MSBFIRST, (upper_byte));
  shiftOut(DAC_SDI, DAC_SCK, MSBFIRST, (lower_byte));
  digitalWrite(DAC_SDI, LOW);
  digitalWrite(DAC_CS, HIGH);
  digitalWrite(DAC_LDAC, LOW);
  digitalWrite(DAC_LDAC, HIGH);
}


void gateIndexShuffle() {
  // Shuffle gateIndex vector
  for (int i = 0; i < 8; i++) {
    int n = random(0, 8);
    int temp = gateIndex[n];
    gateIndex[n] =  gateIndex[i];
    gateIndex[i] = temp;
  }
// end of gateIndexShuffle()
}

void gateIndexReset() {
  // Reset gateIndex vector
  gateIndex[0] = 0;
  gateIndex[1] = 1;
  gateIndex[2] = 2;
  gateIndex[3] = 3;
  gateIndex[4] = 4;
  gateIndex[5] = 5;
  gateIndex[6] = 6;
  gateIndex[7] = 7;
// end of gateIndexReset()
}

void gateIndexReverse() {
  // Reverse gateIndex vector to run sequencer 'backwards'
  gateIndex[0] = 7;
  gateIndex[1] = 6;
  gateIndex[2] = 5;
  gateIndex[3] = 4;
  gateIndex[4] = 3;
  gateIndex[5] = 2;
  gateIndex[6] = 1;
  gateIndex[7] = 0;
// end of gateIndexReverse()
}

void gateIndexFlip() {
  // Flip order of gateIndex vector (a double transpose)
  int temp = 0;
  for(int i=0; i<4; i++){
    temp=gateIndex[i];
    gateIndex[i]=gateIndex[7-i];
    gateIndex[7-i]=temp;
  } 
// end of gateIndexFlip()
}


void gateIndexRoR() {
  // Rotate Right gateIndex vector
  int temp = gateIndex[7];
  for(int i=0; i<7; i++){
    gateIndex[7-i]=gateIndex[6-i];
  } 
  gateIndex[0]=temp;
// end of gateIndexRoR()
}

void gateIndexRoL() {
  // Rotate Left gateIndex vector
  int temp = gateIndex[0];
  for(int i=0; i<7; i++){
    gateIndex[i]=gateIndex[i+1];
  } 
  gateIndex[7]=temp;
// end of gateIndexRoL()
}

void gateAscendingSingleSort(){
  // single pass of Ascending Bubble sort
  for (int i = 0; i<7; i++){   
  if(wA[gateIndex[i]]<wA[gateIndex[i+1]]){
  int temp = gateIndex[i];
  gateIndex[i] = gateIndex[i+1];
  gateIndex[i+1] = temp;
  break;
  }
  }
}

void gateDescendingSingleSort(){
  // single pass of Descending Bubble sort
  for (int i = 0; i<7; i++){   
  if(wA[gateIndex[i]]>wA[gateIndex[i+1]]){
  int temp = gateIndex[i];
  gateIndex[i] = gateIndex[i+1];
  gateIndex[i+1] = temp;
  break;
  }
  }
}

void gateRandomSingle(){
  // generate a random single gateIndex pair change
  int i=random(1,7);
  int temp = gateIndex[i];
  gateIndex[i] = gateIndex[i+1];
  gateIndex[i+1] = temp;
  
}
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

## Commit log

2023-12-12 Rename Hardware/main board schematic.pdf to Hardware/Main/main board schematic.pdf
2023-12-12 Rename Hardware/Main/Main Board Schematic.jpg to Hardware/Main/Graphics/Main Board Schematic.jpg
2023-12-12 Rename Hardware/Main/STRACHEY Main Board Component Side Populated.jpg to Hardware/Main/Graphics/STRACHEY Main Board Component Side Populated.jpg
2023-12-12 Rename Hardware/Control/STRACHEY Control Board Component Side Populated.jpg to Hardware/Control/Graphics/STRACHEY Control Board Component Side Populated.jpg

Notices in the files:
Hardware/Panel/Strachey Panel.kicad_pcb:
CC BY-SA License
